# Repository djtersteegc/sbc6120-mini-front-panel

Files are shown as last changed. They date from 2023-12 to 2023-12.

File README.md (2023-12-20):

cased

Project thread at https://forum.vcfed.org/index.php?threads/sbc6120-mini-front-panel.1245272/

# Switches

The current PCB and dress panel are drilled for miniature toggles with a 6mm diameter bushing/stem.  1/4-40 switches will NOT fit since I wanted a tight fit on the dress panel and the switches are spaced to tightly to use the dress nuts.  Plus, I think this style looks nicer (same as an Altair 8800).

These are commonly listed as MTS-102 (ON-ON) and MTS-112 (ON-Momentary ON) on AliExpress.  I tried all the different red and blue models and ended up using the red ones linked below in the BOM since they had exactly the same length toggles between the two different models.  Total cost shipped to the US for twenty MTS-102 and ten MTS-112 switches was less than ten bucks, versus the $40 it would cost to buy something like E-Switch 100 Series which was the cheapest domestic option I could find.  C&K 7000 series were over $160 for 20 miniature toggles.  Maybe the action is a bit better, but at the end of the day this is a toy for me, so I would personally rather spend the budget on the next project.

# Electrical BOM

There's an interactive BOM [here](https://djtersteegc.github.io/sbc6120-mini-front-panel/ibom.html), and CSV version with footprint info [here](https://djtersteegc.github.io/sbc6120-mini-front-panel/bom.csv).

I buy pretty much everything from UTSource (for logic) or AliExpress suppliers these days with the exception of the capacitors (whatever is on clearance at Newark) and the rotary switch is only available from C&K.  If you are shopping local everything should be available from Mouser/DigiKey/Newark.

Here is a [shared Mouser cart](https://www.mouser.com/ProjectManager/ProjectDetail.aspx?AccessID=54b04bab67) with all the electrical BOM minus the toggle and slide switches which are a China only part.

C16 is a bulk storage cap for the 5V line.  I specced it at 470uF, but anything from 100uF and up will probably be fine.  You may not even really need it.

| Component | Qty  | Notes | Link |
| --- | ---- | --- | --- |
| 10nF Ceramic Capacitor | 1 | 5.08mm Lead Spacing  | [AliExpress](https://www.aliexpress.us/item/2251832786944590.html) |
| 100nF Ceramic Capacitor | 13 | 5.08mm Lead Spacing  | [AliExpress](https://www.aliexpress.us/item/2251832786944590.html) |
| 1uF Ceramic Capacitor | 1 | 5.08mm Lead Spacing  | [AliExpress](https://www.aliexpress.us/item/2251832786944590.html) |
| 470uF 16V Electrolytic Capacitor | 1 | 3.5mm Lead Spacing | [Newark](https://www.newark.com/multicomp-pro/mcmr16v477m8x9/cap-470uf-16v-alu-elec-radial/dp/39T1477) |
| 10K 1% 1/4W Resistor | 3 | | [AliExpress](https://www.aliexpress.us/item/2251832766343175.html) |
| 17.4K 1% 1/4W Resistor | 1 | | [AliExpress](https://www.aliexpress.us/item/2251832766343175.html) |
| 560R SIP9 Resistor Network | 4 | I used 510R | [AliExpress](https://www.aliexpress.us/item/2251832653789055.html) |
| 4.7K SIP5 Resistor Network | 1 | | [AliExpress](https://www.aliexpress.us/item/2251832653789055.html) |
| 4.7K SIP6 Resistor Network | 1 | | [AliExpress](https://www.aliexpress.us/item/2251832653789055.html) |
| 4.7K SIP7 Resistor Network | 3 | | [AliExpress](https://www.aliexpress.us/item/2251832653789055.html) |
| 5mm LED (Red) | 28 | | [AliExpress](https://www.aliexpress.us/item/2255800226642152.html) |
| Miniature ON-ON Toggle | 13 | MTS-102 - 6mm | [AliExpress](https://www.aliexpress.us/item/3256805560180852.html) |
| Miniature ON-(ON) Momentary Toggle | 7 | MTS-112 - 6mm | [AliExpress](https://www.aliexpress.us/item/3256802276750993.html) |
| SPDT Right Angle Slide Switch | 3 | 2.54mm Spacing | [AliExpress](https://www.aliexpress.us/item/2251832665517359.html) |
| C&K RM104772BCB Rotary Switch | 1 | 4 Position | [Newark](https://www.newark.com/c-k-components/rm104772bcb/rotary-switch-1p-0-5a-24v-45deg/dp/69AH1990) |
| 74HC05 | 1 | | |
| 74HC74 | 1 | | |
| 74HC174 | 2 | | |
| 74HC366 | 4 | | |
| 74HC373 | 2 | | |
| 7555 Timer | 1 | | |
| ATF16V8 | 1 | | |
| ATF22V10 | 1 | | |
| 2x25 2.54mm Pin Header | 1 | | [AliExpress](https://www.aliexpress.us/item/2251832485909733.html) |
| 1x2 2.54mm Pin Socket | 1 | Cut down a 40p strip | [AliExpress](https://www.aliexpress.us/item/2251832484668248.html) |
| 5.08mm 2p Terminal Block (or original 4P Molex) | 1 | KF301-2P (Power In)  | [AliExpress](https://www.aliexpress.us/item/2251832480927324.html) |

# Mechanical BOM

| Component | Qty  | Notes | Link |
| --- | ---- | --- | --- |
| 12mm M3 Standoff | 5 | SBC6120 to Panel | 3D Print |
| 15.6mm M3 Standoff | 7 | Panel to Dress Panel | 3D Print |
| 2mm High M3 Rubber Bumpers | 7 | TS-2.7 Option | [AliExpress](https://www.aliexpress.us/item/3256805089368820.html) |
| M3 x 6mm Taper Head Screws | 12 | | [AliExpress](https://www.aliexpress.us/item/3256801858523146.html) |
| M3 x 12mm Taper Head Screws  | 5 | | [AliExpress](https://www.aliexpress.us/item/3256801858523146.html) |
| M2.5 x 6mm Taper Head Screws | 6 | | [AliExpress](https://www.aliexpress.us/item/3256801858523146.html) |
| 15mm Diameter Knob | 1 | "Plum Shaft" Option  | [AliExpress](https://www.aliexpress.us/item/2251832788673272.html) |

# Other Parts

| Component | Notes | Link |
| --- | --- | --- |
| IDE to CF Adapater | CF-IDE40 or HX-168 | [AliExpress](https://www.aliexpress.us/item/3256804514420229.html) |
| DB9 to IDC 10 | May need to rewire | [AliExpress](https://www.aliexpress.us/item/3256803077047244.html) |
| 5.5 x 2.1mm DC Input Jack for 8mm Hole | DC-025M | [AliExpress](https://www.aliexpress.us/item/2255801022148508.html) |

# Case

The case is a simple two piece that holds the SBC6120 and front panel PCB securely to the bottom plate, and then the dress panel is held down by pressure around it's perimeter by the case top.  You will need supports on the bottom plate for CF, DB9, and DC power openings, but everything else can be printed without.  I would recommend a 0.2mm layer height since most dimensions are a multiple of that.  The case top and plate are 214mm x 135mm so they should be printable on something like a standard Ender 3.

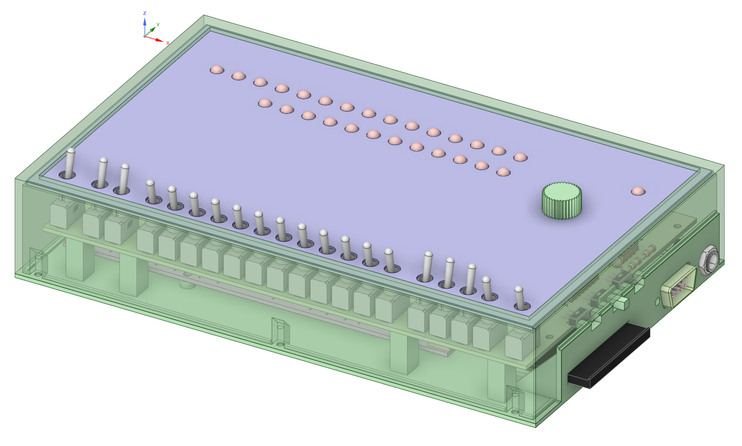
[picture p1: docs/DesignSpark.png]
DesignSpark


Total PLA filament usage for all part is ~146 grams according to Cura 5.5.

| Part | Qty  | Filament Usage (PLA) |
| --- | ---- | --- |
| Case Top | 1 | 68g |
| Bottom Plate | 1 | 64g |
| Switch Spacer | 20 | 5g |
| M3 x 12mm Standoff | 5 | 2g |
| M3 x 15.6mm Standoff | 7 | 3g |
| Slide Switch | 3 | 1g |
| Reset Button | 1 | <1g |
| Rotary Knob Adapter | 1 | 1g |
| 2.4mm Spacer for LED Installation | 4 | 1g |

Design file are in the [DesignSpark](3D/DesignSpark) folder if you would like to modify further or tweak tolerances for your printer. 

# Assembly

Build the PCB from low to high components, savings the switches, LED's, and pin headers for last. Pay attention to the Run (D28) LED, it's orientation is flipped vs. all the others. The rotary switch has a small notch, it MUST be lined up with the tick on the silkscreen. There is no other keying on this switch so it can be installed incorrectly.

Print out six copies of the [M3 x 15.6mm Standoff](3D/STL/M3%20x%2015.6mm%20Standoff.stl) if you are using the 2mm high rubber inserts on top of them, or use the [M3 x 17.6mm Standoff](3D/STL/M3%20x%2017.6mm%20Standoff.stl) if you are not.

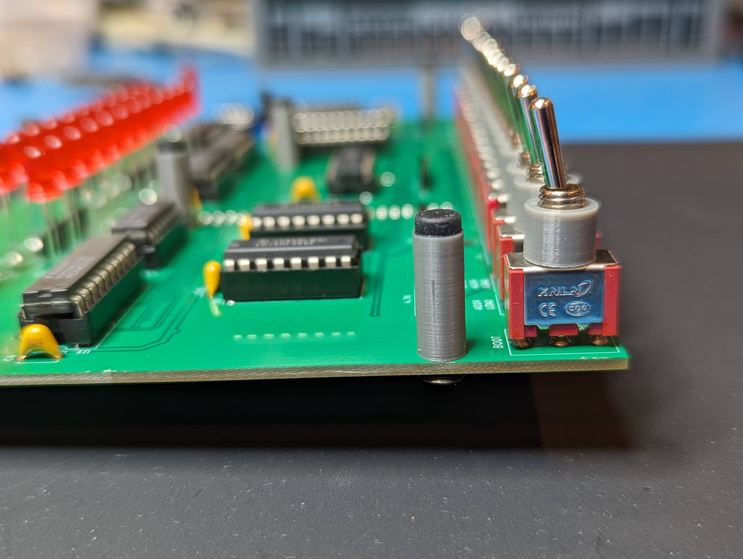
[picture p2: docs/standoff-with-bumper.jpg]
standoff-with-bumper


Also print out 20 copies of the [Switch Spacer](3D/STL/Switch%20Spacer.stl).

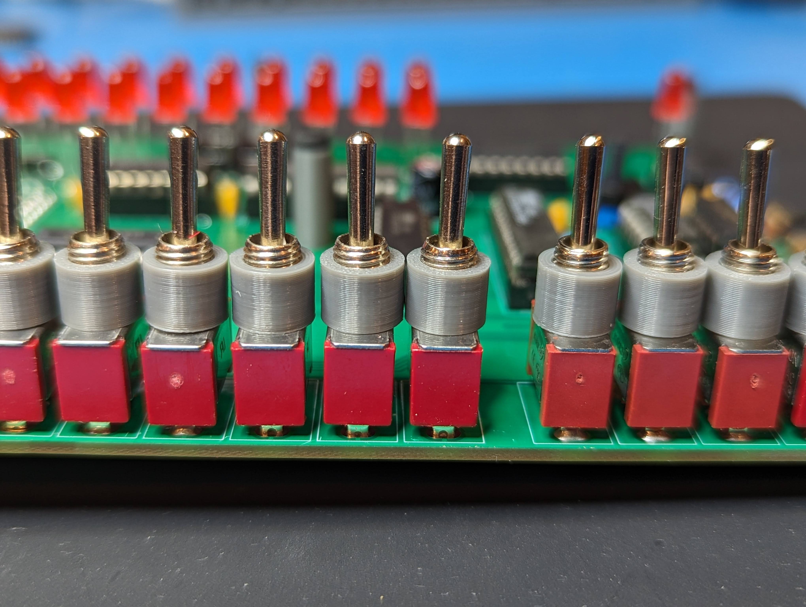
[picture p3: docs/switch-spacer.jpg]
switch-spacer


Screw the standoff into the front panel PCB, place all the switches, paying attention to the ON-ON vs. ON-(ON) models. All momentary switches should face up with the exception of the Dep (SW19) which faces down when not activated.

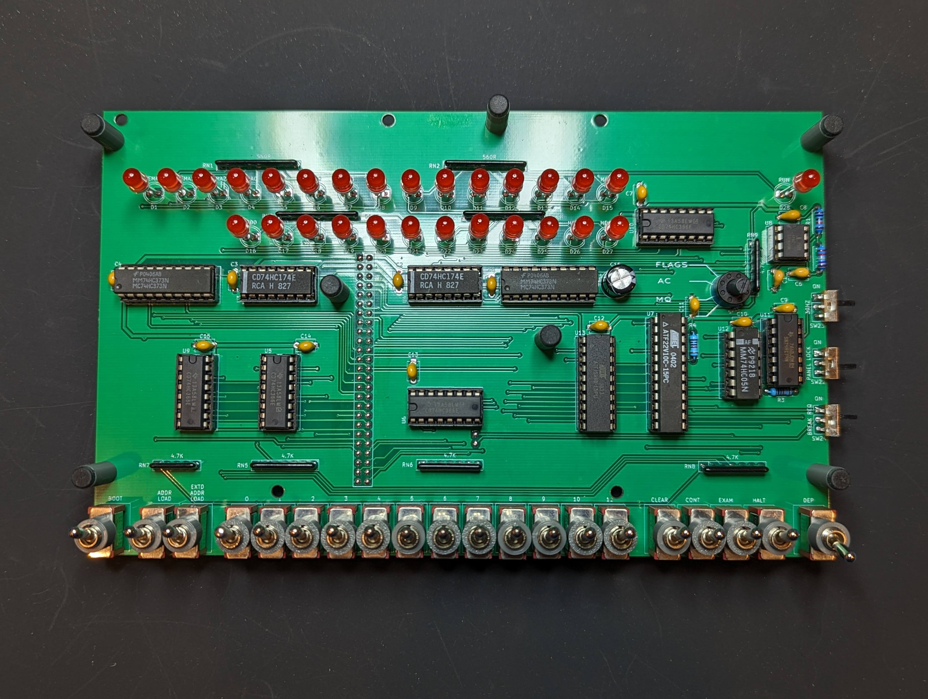
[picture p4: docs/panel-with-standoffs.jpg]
panel-with-standoffs


Slip the 20 switch spacers onto the stems, and place the dress panel so it is resting on top of the standoffs and switch spacers.  It helps to have all the switches facing up (except for DEP), slip the panel over the DEP switch, and then rotate counterclockwise to drop over the rest of the switches.  Flip everything over and rest the dress panel on something to elevate it above your work surface so the switch stems hang down.  I found a 3/4" piece of plywood worked well for this.  While supporting the dress panel, push all the switch PCB lugs down so there is no slack between the top of the switch body, spacer, and dress panel.  This will give you a consistent reveal on the front panel even if the Chinese switch tolerances are a little off and/or switch won't sit flat on the PCB due to excess sealing epoxy applied on the bottom of it.  Solder them all in.  I did one terminal each, flipped over to check my work, and then did the rest.

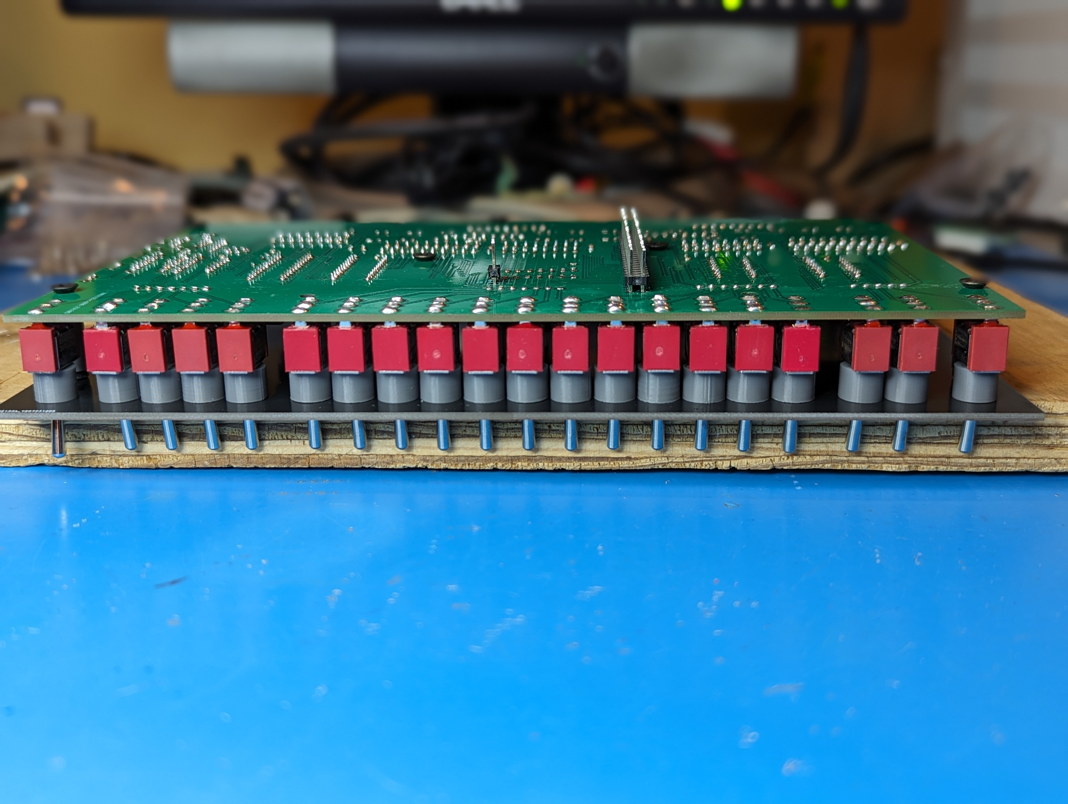
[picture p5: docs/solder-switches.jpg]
solder-switches


For the LED's, remove the dress panel, drop in the 28 LED's (since I was using cheap Chinese one's I tested them all before to make sure they were all the same brightness, they were), and then flip everything over again until the LED's poke through the dress panel holes.  I elected to have 2.4mm of reveal/protrusion on the LED's, so print out four of the [2.4mm LED Spacer](3D/STL/2.4mm%20LED%20Spacer.stl) pucks and place them under the four corners of the dress panel.  Again, the 3/4" plywood allowed the panel to lay flat while the switches overhung the edge.  Solder one leg each on the LED's, flip over to check your work, and then do the others.

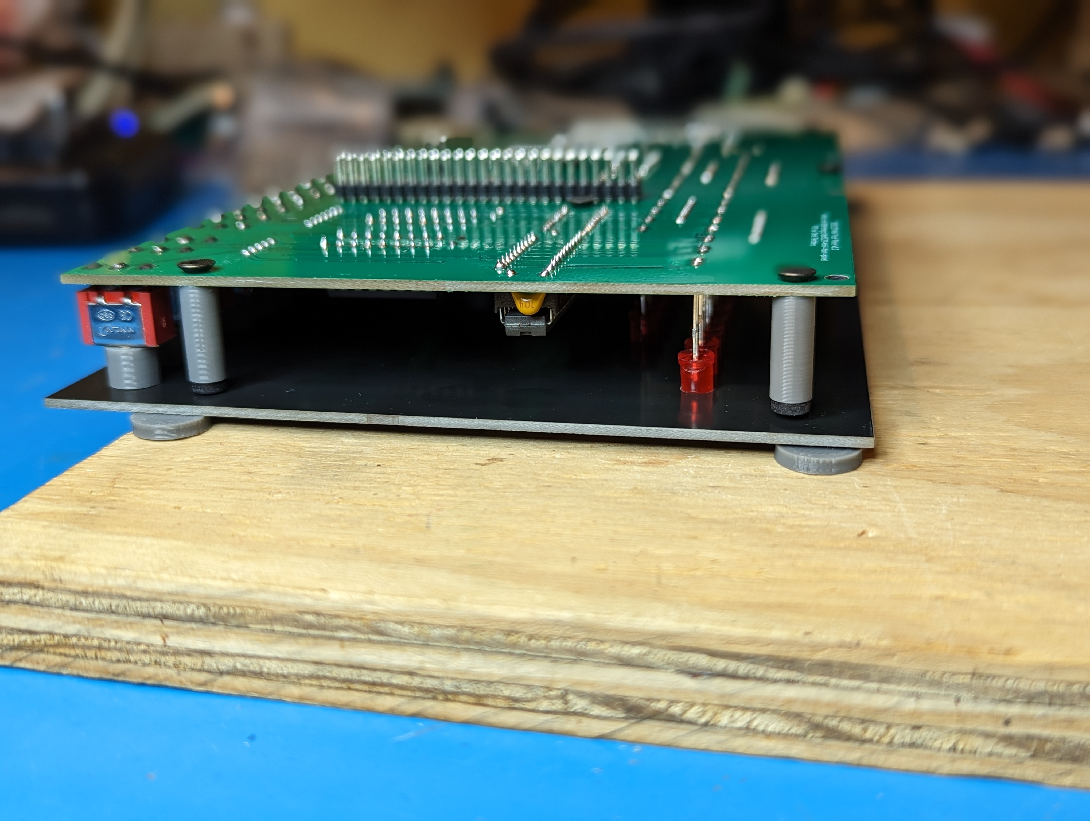
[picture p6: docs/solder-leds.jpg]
solder-leds


To install the pin headers first print and then install five [M3 x 12mm Standoff](3D/STL/M3%20x%2012mm%20Standoff.stl) on the SBC6120.  I went with 12mm instead of the more common 11mm since my socketed HD6120 was sitting at ~10mm and even after trimming the DIP socket and resistor network leads flush above it, it still seems a little tight for my tastes.  I also switched the CPREQ male header on the SBC6120 to a female header like the 2x25mm and that allowed me to fully install the male headers into both of them, and then place the front panel PCB on top and solder everything up. The header pins should be just flush with the top of the front panel PCB, not protruding like you would see with a normal install.

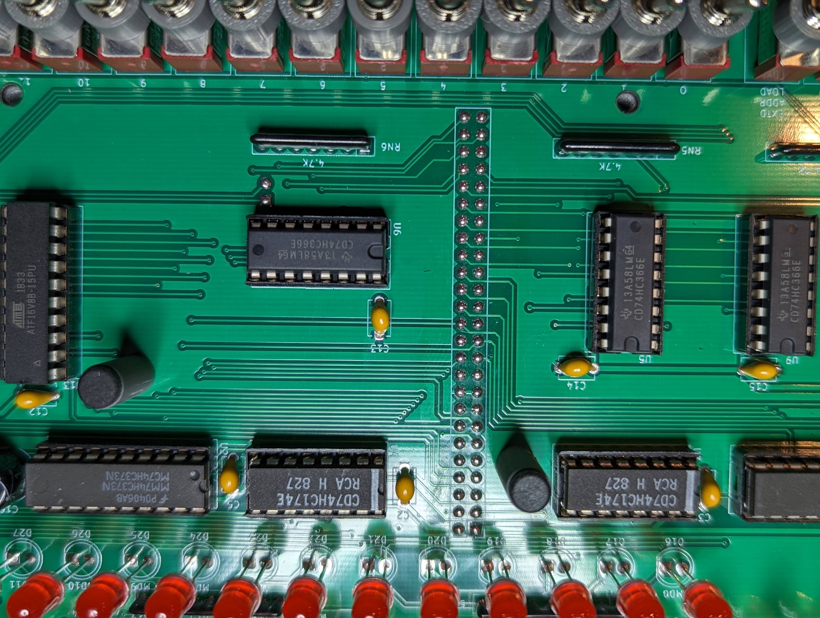
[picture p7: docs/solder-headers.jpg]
solder-headers


At this point you can install your IC's and make sure everything works.  JED files for the ATF16V8 and ATF22V10 are in the [Original STG FP6120 Files/pld](Original%20STG%20FP6120%20Files/pld) folder.  ATF16 gets decode.jed, ATF22 is control.jed. Now onto casing your new toy.

Plug the CF adapter, DB9, and DC input jack into the SBC6120.  Remove the 12mm standoffs, and install the SBC6120 to the [Bottom Plate](3D/STL/Bottom%20Plate%20-%20CF-IDE40.stl) with five M3x12mm screws into the bottom of the standoffs.

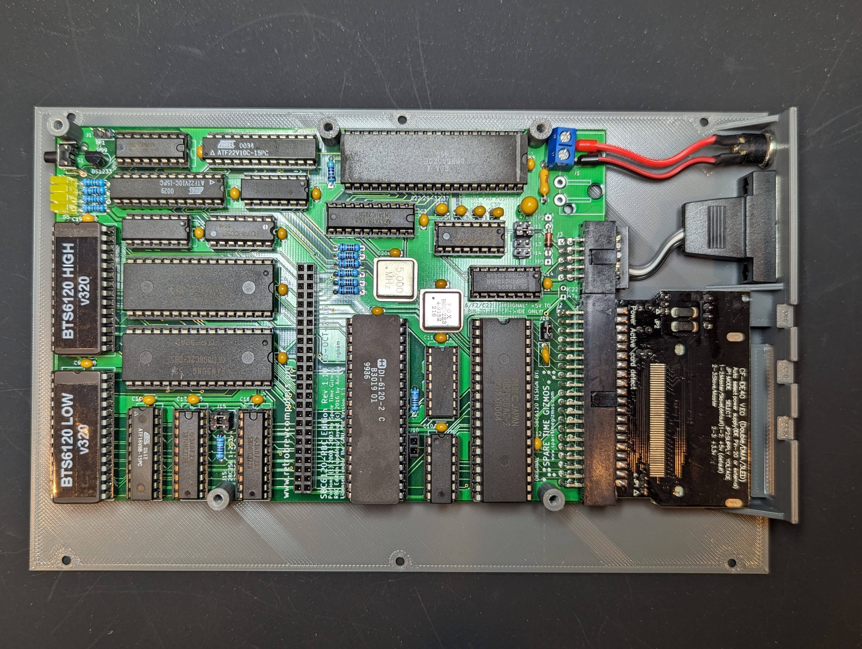
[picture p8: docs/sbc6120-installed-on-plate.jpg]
sbc6120-installed-on-plate


Slip three of the [Slide Switch](3D/STL/Slide%20Switch.stl) extenders onto the switches and install the front panel PCB onto the SBC6120.  Secure with five M3x6mm screws.

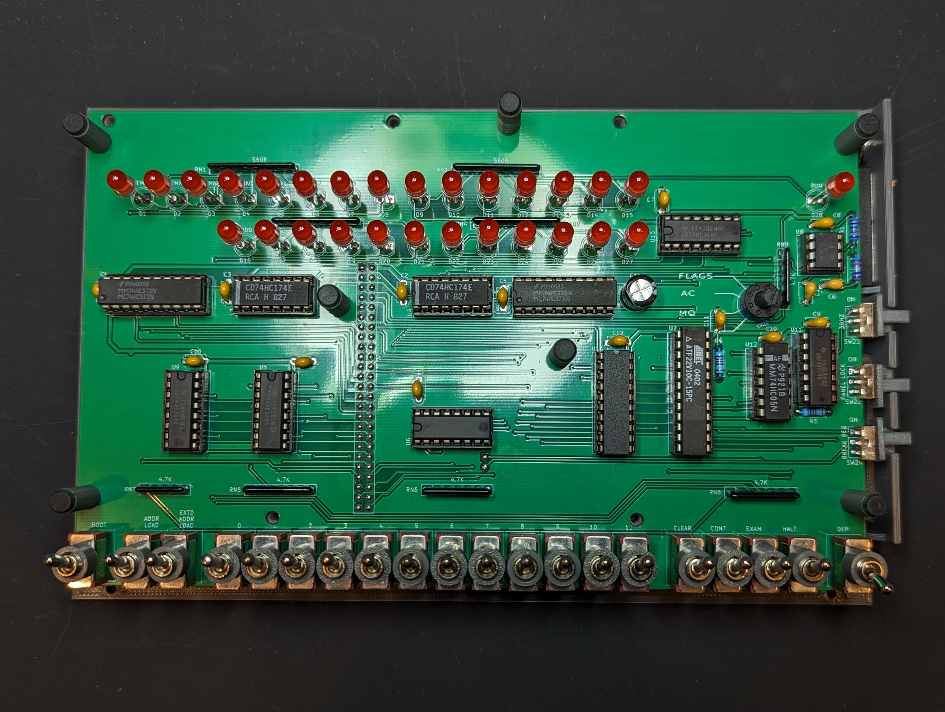
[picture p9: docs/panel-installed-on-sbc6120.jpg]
panel-installed-on-sbc6120


Angle the dress panel PCB into the [Top Case](3D/STL/Top%20Case.stl) and make sure it fits in the recess at the top.

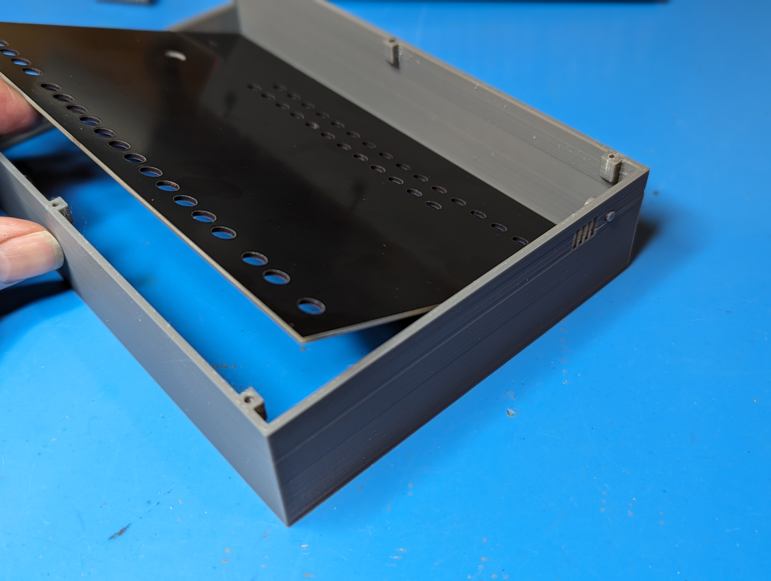
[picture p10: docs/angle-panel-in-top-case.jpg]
angle-panel-in-top-case


Install the [Reset Button](3D/STL/Reset%20Button.stl) extender into the hole and then let the dress panel rest at the bottom of the top case on top of the six lugs for the screws. Place over the switches with a similar counterclockwise twisting motion as above, and then push the top case all the way down.

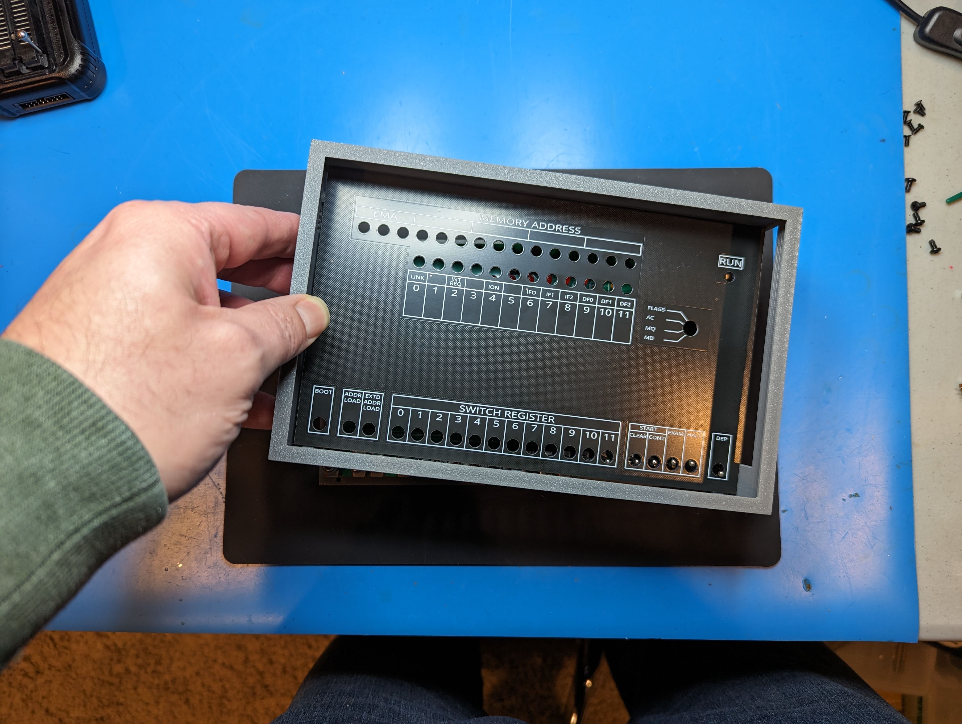
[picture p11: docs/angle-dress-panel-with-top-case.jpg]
angle-dress-panel-with-top-case


Secure with six M2.5x6mm screws through the bottom of the case.

Finally push the splined portion of the [Rotary Knob Adapter](3D/STL/Rotary%20Knob%20Adapter.stl) into your 6mm knob with the D cut opposite the indicator mark on the switch, and line up the D cut on the rotary switch.

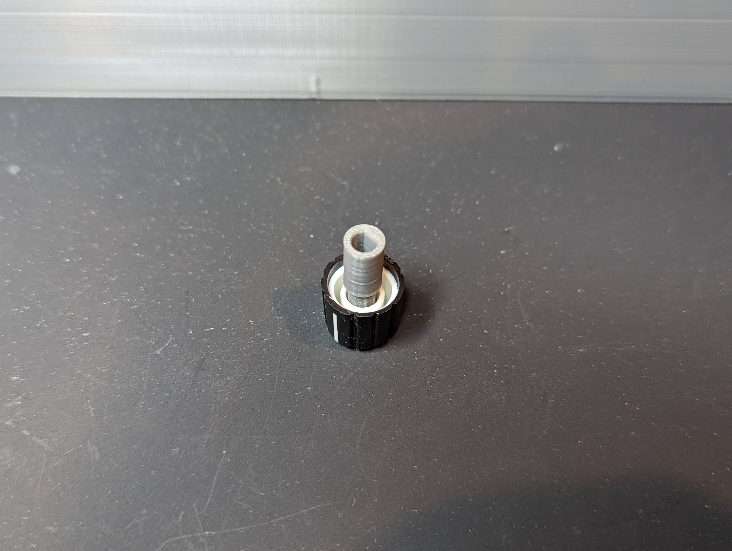
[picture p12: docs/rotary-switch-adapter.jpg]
rotary-switch-adapter


# How do I get some PCB's?

If you are in the US, hit me up on the VCF forum thread above and if I have any extras, I can drop some in the mail for less than the cost of a small run at JLCPCB (size and shipping drive up the costs here).  Otherwise, there are gerber files available for use at your favorite PCB fab.

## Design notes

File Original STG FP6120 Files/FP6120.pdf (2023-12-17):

Copyright 2003 by Spare Time Gizmos.

### Visit our web site at www.SpareTimeGizmos.com

Permission is granted to copy, distribute and/or modify this document under the terms of the GNU Free Documentation License, Version 1.1 published by the Free Software Foundation; with no invariant sections; with the front cover text “Portions Copyright 2001-2003 by Spare Time Gizmos” and our URL, and with no back cover text. A copy of this license may be obtained from http://www.gnu.org/licenses/fdl.txt.

FP6120

# SBC6120 FRONT PANEL

# USER'S MANUAL

# First Edition

# CONTENTS

Page i

Spare Time Gizmos | FP6120 User's Manual

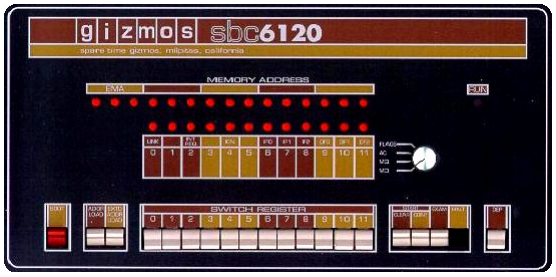
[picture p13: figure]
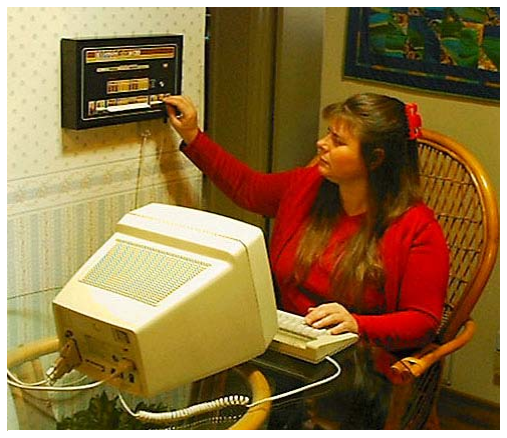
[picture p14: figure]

10/24/2003 8:39 PM | Page 1

# 1 OVERVIEW

The FP6120 adds a traditional PDP-8/E style Programmer’s Console to any SBC6120 system. Twenty seven
LEDS provide
continuous
display of the
current
memory
address as
well as
memory or
register
contents, and
a additional
LED displays
the running or
halted state of
the processor.
Twelve data
switches allow
for direct entry of binary data and an additional eight switches provide program control functions
including BOOT, ADDRESS LOAD, EXTENDED ADDRESS LOAD, CLEAR, CONTINUE, EXAMINE, DEPOSIT
and HALT.

The FP6120 is designed as a peripheral device which plugs into the standard SBC6120 expansion bus, however because of its physical size the SBC6120 actually mounts directly to the back of the front panel. Additional space is available on the back of the FP6120 to mount another I/O board as well as either a CompactFlash memory card or a standard 2½” laptop hard disk drive. Finally, the FP6120 contains a switching power supply which can supply all necessary power for the SBC6120, one or two daughter boards, and the FP6120 itself from a single unregulated source of +9 to +12VDC.

The front panel façade you see in these photos was professionally screen printed in five colors and then laser cut for the switch openings. The entire FP6120 and SBC6120 assembly, including a hard disk drive, is less than 2” thick and can be framed like a painting and hung on the wall. Just imagine it – a complete PDP-8/E clone, including disk drive, hanging on the wall above your desk!

### 1.1 REGULATORY WARNING

In the United States, the Federal Communications Commission requires that devices that use and radiate radio frequency energy be certified in accordance with CFR Title 47, Parts 2 and 15. Other countries will have different requirements.

Figure 1 - The SBC6120 Front Panel

Figure 2 - Complete SBC6120/FP6120 combination hanging on the wall

The FP6120 design is not in finished product form and has NOT been approved by the FCC or any other regulatory agency worldwide. The user understands that approvals may be required prior to the operation of the FP6120, and agrees to utilize the FP6120 in keeping with all laws governing its operation in the country of use.

### 1.2 WARRANTY

SPARE TIME GIZMOS OFFERS NO WARRANTY, EXPRESS OR IMPLIED, AS TO THE RELIABILITY OR ACCURACY OF THE FP6120 DESIGN. SPARE TIME GIZMOS OFFERS NO WARRANTY, EXPRESS OR IMPLIED, AS TO THE ACCURACY OF THE INFORMATION PRESENTED IN THIS DOCUMENT. SPARE TIME GIZMOS OFFERS NO WARRANTY, EXPRESS OR IMPLIED, AS TO THE SUITABILITY OR CORRECTNESS OF ANY SOFTWARE OR FIRMWARE SUPPLIED IN CONJUNCTION WITH THE FP6120.

SPARE TIME GIZMOS MAKES NO REPRESENTATIONS AS TO THE SUITABILITY OF THE FP6120 FOR ANY APPLICATION. IT IS SOLELY AND EXCLUSIVELY YOUR RESPONSIBILITY TO EVALUATE THE ACCURACY, COMPLETENESS, AND USEFULNESS OF THE FP6120 AND ALL RELATED DESIGNS, SOFTWARE, AND OTHER INFORMATION PROVIDED BY SPARE TIME GIZMOS. THE ENTIRE RISK AS TO THE USE AND PERFORMANCE OF THE FP6120 IS ASSUMED SOLELY BY YOU.

NO REPRESENTATION OR OTHER AFFIRMATION OF FACT, INCLUDING, BUT NOT LIMITED TO, STATEMENTS REGARDING CAPACITY, PERFORMANCE OF PRODUCTS, OR SUITABILITY FOR USE, WHETHER MADE BY SPARE TIME GIZMOS EMPLOYEES OR OTHERWISE, WILL BE DEEMED TO BE A WARRANTY FOR ANY PURPOSE, OR GIVE RISE TO ANY LIABILITY ON THE PART OF SPARE TIME GIZMOS.

THE WARRANTIES AND CORRESPONDING REMEDIES AS STATED IN THIS SECTION ARE EXCLUSIVE AND IN LIEU OF ALL OTHERS, WRITTEN OR ORAL. SOME JURISDICTIONS DO NOT ALLOW THE EXCLUSION OF IMPLIED WARRANTIES, SO THE ABOVE EXCLUSION MAY NOT APPLY TO YOU. THE LIMITED WARRANTIES AND CONDITION REFERENCED ABOVE GIVE YOU SPECIFIC LEGAL RIGHTS. YOU MAY HAVE OTHERS, WHICH VARY FROM JURISDICTION TO JURISDICTION.

IN NO EVENT SHALL SPARE TIME GIZMOS OR ITS EMPLOYEES BE LIABLE FOR ANY COSTS OR DIRECT, INDIRECT, PUNITIVE, INCIDENTAL, SPECIAL, CONSEQUENTIAL DAMAGES OR ANY OTHER DAMAGES WHATSOEVER INCLUDING, WITHOUT LIMITATION, DAMAGES FOR COSTS OF PROCUREMENT OF SUBSTITUTE GOODS OR SERVICES, LOST PROFITS, LOSS OF DATA, INTERRUPTION OF BUSINESS, OR LOSS OF USE, ARISING OUT OF OR IN ANY WAY CONNECTED WITH THE USE OR PERFORMANCE OF THE FP6120 OR YOUR RELIANCE ON THE FP6120 OR RESULTS FROM MISTAKES, OMISSIONS, INTERRUPTIONS, DELETION OF FILES, ERRORS, DEFECTS, DELAYS IN OPERATION OR TRANSMISSION, OR ANY FAILURE OF PERFORMANCE WHETHER BASED ON CONTRACT, TORT, STRICT LIABILITY OR OTHERWISE, EVEN IF SPARE TIME GIZMOS HAS BEEN ADVISED OF THE POSSIBILITY OF DAMAGES. BECAUSE SOME STATES/JURISDICTIONS DO NOT ALLOW THE EXCLUSION OR LIMITATION OF LIABILITY FOR CONSEQUENTIAL OR INCIDENTAL DAMAGES, THE ABOVE LIMITATION MAY NOT APPLY TO YOU.

IN NO EVENT SHALL SPARE TIME GIZMOS' LIABILITY, IN THE AGGREGATE, EXCEED THE SUMS ACTUALLY PAID BY YOU TO SPARE TIME GIZMOS AND ACCEPTED BY SPARE TIME GIZMOS FOR THE USE OF THE
FP6120.

# 2 CONSTRUCTION

If you haven’t already, then please read the “Assembly” section of the SBC6120 User’s Manual before reading this. Many of the points made there, particularly the section on “Sockets and Soldering” apply equally well to the FP6120!

### 2.1 ERRATA

There are no known errors in Revision D of the FP6120 board.

### 2.2 FIRMWARE NOTES

The FP6120 requires that your SBC6120 have BTS6120 v266 or later. This version may be downloaded from the Spare Time Gizmos web site if you need to upgrade your EPROMs. The FP6120 does not require any changes to the SBC6120 PLDs.
If you intend to use the FP6120 with Jim Kearney's IOB6120, there are more issues you should be aware of:
- The IOB6120 requires a hardware upgrade to work reliably with the FP6120. The last few IOBs assembled and sold by Jim already had this modification, and if your IOB contains a 74HC373 part then yours should be OK. If it contains a 74ACT373, however, talk to Jim about the details of a fix.
- Early versions of the FPGA bit stream include an implementation of the PDP-8 switch register which will conflict with the FP6120 and prevent the front panel switches from working. The latest version of the FPGA bit stream has the switch register removed and can be obtained from http://www.jkearney.com/sbc6120/iob6120.htm. Follow the instructions in Jim’s IOB6120 manual for downloading new FPGA bits to the Flash ROM on the IOB6120.
- Although the FP6120 works with any SBC6120 PLD version, the IOB requires revision B or later of the IOT1 PLD. Spare Time Gizmos is currently shipping revision C of this part. Contact Jim directly for more information on these IOB updates.

### 2.3 SBC6120 MODIFICATIONS

SBC6120 Revision D PC boards require that a jumper be added to connect the LXMAR signal to pin 22 of the expansion connector. Revision E and later PC boards incorporate this change and do not require modification. The revision of your PC board can be found in the etch on the solder side underneath the IDE connector – look for the words “SBC6120-2x Copyright 200? Spare Time Gizmos”. The letter “x” after the SBC6120-2 is the revision of your board.
Figure 3 shows the proper way to modify a revision D PC board. Carefully count the pins on the bus connector to locate pin 22, and then count down four more pins to locate the trace that connects U8 pin 23 to U5 pin 34. This trace is LXMAR, and you need to solder a short jumper from it to pin 22 of the bus connector. Since pin 22 was previously unused, no other traces need to be cut.

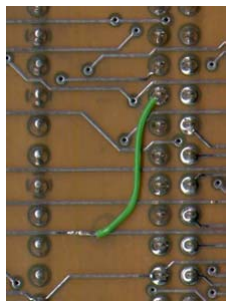
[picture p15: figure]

Spare Time Gizmos is currently shipping Revision E of the SBC6120 PC boards. These boards, and later ones, already incorporate this

Figure 3
LXMAR Jumper connection and do not require modification.

### 2.4 PARTS SELECTION

### 2.4.1 Finding Compatible Switches

The FP6120 is designed to use C&K P/N 7101J60V6BE1 (ON-NONE-ON) and 7108J60V6BE1 (ON-NONE-MOM) SPDT PCB mount paddle switches. It’s certainly possibly to find exact matches for these part numbers, however there are a number of other switches that can also be used. It's handy to understand something about the C&K nomenclature so you can figure out possible substitutions.
J60 is the actuator style, in this case a 0.460" wide lever. Other styles in the same width, such as the J1, J15 or J50 rockers, will fit the PC board but probably won't work with the plastic front facade. It’s also worth nothing that the actuators are interchangeable between the C&K paddle and rocker switches, so if you have a cheap source for ON-NONE-ON paddle switches, it’s possible to remove the paddles from them and install them on the corresponding ON-NON-(MOM) rocker switches.
V6 refers to the PCB mount frame used. The V61 frame is for our purposes identical and will work without problems. The V3 and V31 frames are similar but with different mounting hole spacing, however the FP6120 PC board contains extra holes so that the V3 and V31 frames will also fit without problems. The V2 and V21, V4 and V41, V7, V8, and V9 frames will all fit the PC board however these frames are different heights and will not mate properly with the plastic front panel faceplate.
B refers to the contact material (gold in this case), which is unimportant as far as mechanical concerns go. The only other one you're likely to see is Q, silver.
The final 1 at the end of the P/N is the actuator color. 1 is White, 2 is Black, and 3 is Red. Naturally this makes to mechanical difference, but, for example, you might not like the way a row of all red switches looks!
Finally, C&K is not the only possible switch source. Other manufacturers, such as NKK, E-Switch, CTS, etc. make switches that are generally compatible with their C&K counterparts. These manufacturers usually have some sort of cross reference guide to help you find equivalent part numbers.

### 2.4.2 The LED Bar

The LED Bar is a piece of plastic, approximately 12.4"x1.1" and 5/8" thick with holes drilled in it for every LED. It mounts solder in swage standoffs placed on the PC board with #4-40 screws and serves two purposes. First, the LED bar serves as an "aligner" to keep the LEDs straight and lined up with the corresponding holes in the faceplate. Second, the bar isolates the LEDs so that the light from, say, the MA3 LED doesn't also leak out the opening for the MA2 or MA4 LEDs. You can build your own LED bar, or you can purchase a nicely milled and drilled one all ready to go directly from Spare Time Gizmos, part number FP6120-LBK.

### 2.4.3 The Faceplate

The faceplate is a piece of 3/16” acrylic plastic, approximately 8 ½” by 15”, silk screened with the front panel graphics and cut to clear the switches. It mounts to the front panel PC board with eight #4-40 by 5/8” standoffs which are permanently attached to the faceplate. You can purchase a faceplate separately from Spare Time Gizmos, part number FP6120-FPK.
In the faceplate supplied by Spare Time Gizmos the graphics are screen printed, with no less than five colors and five separate printing steps, onto a 15 mil (that's 0.015"!) polycarbonate film.

In a separate step a 3/16" thick piece of acrylic is laser cut to size and drilled for the mounting holes. The mounting hardware is then attached to the back of this panel and permanently glued into place. In yet a third separate step, a sheet of adhesive film is cut to size and then stamped with a custom made die to cut out circular openings in the exact size and position of the LED windows. Now, those three separate pieces, the film with the graphics, the adhesive, and the 3/16" panel are all laminated together into a single piece and finally the entire thing is laser cut again for the switch openings.
One nice feature of process is that the faceplate is all one piece when you get it, so there's no complex assembly required on your part (like aligning and sandwiching a film between two sheets of plastic). Another nice feature is that the silkscreen is actually printed on the back side of the polycarbonate film, so that when it's assembled all the printing is protected from wear and scratches by the 15 mil thick film. And finally, this style of assembly hides leaves the heads of the mounting screws hidden beneath the film, so there’s nothing to mar the faceplate graphics.

### 2.4.4 Integrated Circuits

Either the 74HC366 or 74HC368 Hex Inverting Tri-State buffer may be used in this circuit.¹
The
7555 CMOS timer is known by many different part numbers depending on the manufacturer. The actual 7555 part number is used by Harris/Intersil, however the TLC555 (manufactured by Texas Instruments) is also quite common. The Power Trends (now part of Texas Instruments) switching regulator is available in either a 2A/10W version, the PT78HT205H or a 3A/15W version, the PT78HT305H. Either one will fit the PC board, and you may wish to use the 3A/15W device if you plan to also power a hard disk drive.²

### 2.4.5 Other Parts

C2 and C7 are 0.01 µF monolithic capacitors and are shown on the schematic and PC board, however they are not needed and may be omitted from the FP6120. It does no harm to install them, though, and if you already have then there’s no need to remove them.

### 2.5 ASSEMBLY INSTRUCTIONS

In the following instructions, the "front" of the PC board refers to the component side (the one with the silk screen) and the "back" of the PC board is the solder side (opposite the silk screen). The "top" of the PC board is the edge that contains the Spare Time Gizmos logo, and the "bottom" of the PC board is the edge with all the switches.

### 2.5.1 Swage Standoffs

Solder in, swage, ⅛” by #4-40 standoffs are used to mount the LED bar, the SBC6120 and an I/O daughter board (if any). Some of these standoffs are mounted on the front (component) side of the PC board and some are mounted on the back (solder) side, and it’s very important to identify the correct holes for each standoff.

1 If you purchased the kit version, either part may be supplied. 2 The PT78HT205H is supplied with the full kit.

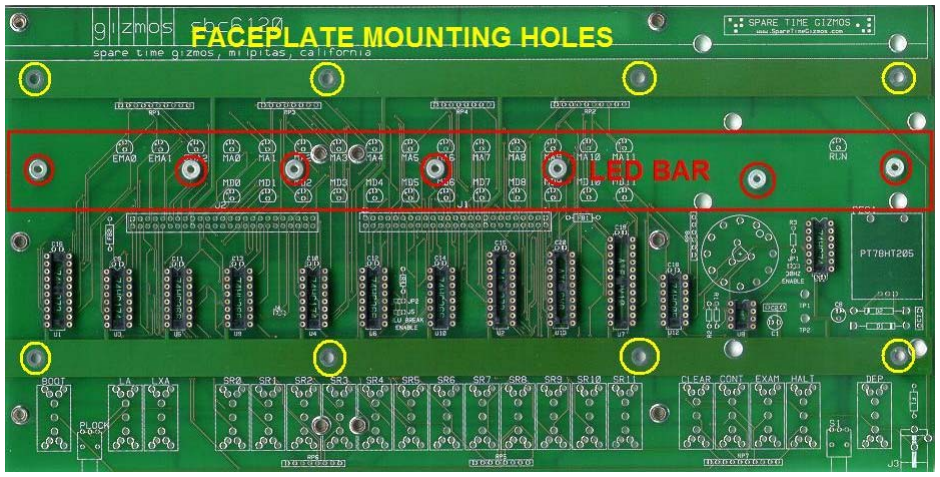
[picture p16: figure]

Figure 4 -Mounting Holes (Component Side)

Figure 4 shows the component side of a partially assembled FP6120 PC board. The outline of the LED bar is shown and the seven swage standoffs used for mounting the LED bar are circled. These standoffs are all mounted with their threaded parts on the front (component) side of the PC board and are soldered on the back (solder) side.
Figure 4 also shows the eight mounting holes used by the faceplate assembly. These holes do not use swage standoffs!
Figure 5 shows the solder side of the same FP6120 PC board and the outlines of the SBC6120 board, the I/O board, the CompactFlash adapter, and the IDE disk drive. The colored circles indicate the corresponding mounting holes for each device. The SBC6120 and I/O board each use five swage standoffs, and in this case the standoffs are installed with their threaded part on the solder side of the PC board and are soldered on the component side.

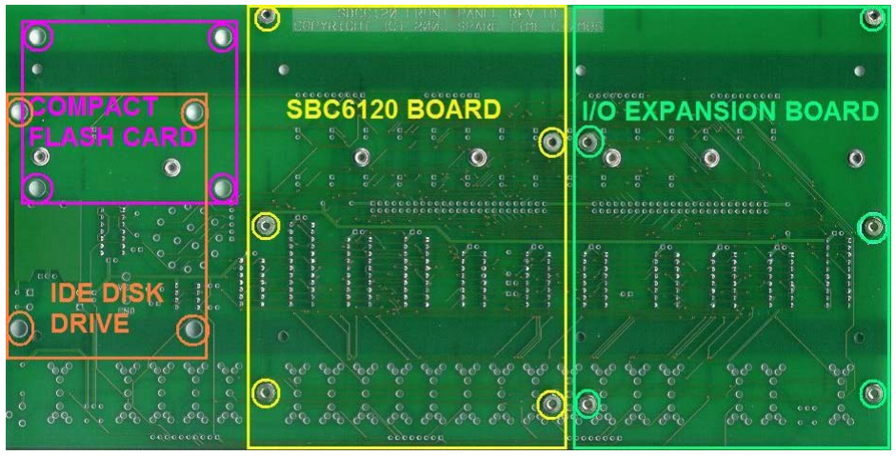
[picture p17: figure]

Figure 5 - Mounting Holes (Solder Side)

### 2.5.2 Small Components

9 Mount the small components, such as the IC sockets, resistors, capacitors, and the voltage regulator REG1, next. Above all, do not mount the LEDs, switches, or connectors now.
9 All the resistor packs used are the type that has one common pin. Be sure to mount them with the common pin as #1, which is indicated by a square pad on the PC board. You may wish to socket RP1 thru RP4 if you want to change them later to adjust the LED current³ .
RP5 thru RP8 are always 4.7K and there's no point in socketing them.

### 2.5.3 Power Switch, Panel Lock and Power Connector

9 The power switch (S1), panel lock switch (PLOCK) and DC power connector (J3) may all be mounted directly to the PF6120 PC board. However, if you plan to install the FP6120 in an enclosure of some kind it may be more convenient to mount these switches off the PC board, or even remove them all together.
The panel lock switch (PLOCK) may be omitted without problems (it will default to unlocked if it is not installed) or you may connect it to an external switch (perhaps a key switch or some kind) using wire jumpers.
If you mount the power switch (S1) elsewhere it’s probably easier to simply wire it in series with the power supply rather than connecting it to the pads for S1 on the PC board. If you do this, be sure to solder a wire jumper between the pads for S1 on the FP6120 PC board to provide continuity for the power circuit!
If you mount the DC power jack, J1, off the PC board be careful of the polarity – the center pin is positive and the sleeve is negative!

3 Sockets for these resistor packs are not included in the FP6120 full kit.

### 2.5.4 Bus Connectors

9 J2 is a female, non-stacking bus connector which you should mount on the solder side of the PC board. You will be soldering its pins on the component side.
9 J1 is a stacking bus connector which you should mount with the female part on the component side of the PC board. The stacking pins should extend thru the solder side, and you solder it normally, on the solder side. Try to keep the solder down around the pads when soldering this connector, and don't get any solder on the ends of the pins.
9 J5 is a two pin female header which mates with the console CPREQ header on the SBC6120. That’s the two pin header immediately to the right of the HD6120 CPU chip. J5 should be installed on the back side of the front panel PC board. You may also need to replace the header on the SBC6120 with one that has longer pins (the wire wrap style are plenty long) to ensure that it makes connection with J5⁴
Having said that, be sure that the pins aren't too long - you could crack the PC board when you tighten the mounting screws on the SBC6120! In particular, if you do you replace the header on the SBC6120 with a wire wrap version, the pins will be way too long! The best procedure is to insert the wire wrap header in the SBC6120 PC board without soldering it (you can use tape to hold it in place) and then temporarily mount the SBC6120 on the back of the FP6120 PC board (see section 0). You can push the pins on the wire wrap header thru the SBC6120 PC board until the correct length is achieved. Then solder them, remove the SBC6120 from the FP6120, and cut off the excess pin length.
Don't confuse J5 with JP2 (the SLU Break Enable jumper) on the front panel PC board. JP2 is closer to the resistor and is a standard two pin header installed on the top of the front panel PC board. J5 is the pair of holes closest to the switch register.
9 J4 serves a similar purpose connecting to the CPREQ header on the IOB6120 board. In this case you should have installed a female header on the back side of your IOB and the male header on the back side of the front panel. This arrangement allows you to plug the IOB6120 into the SBC6120 directly, without a front panel, if you ever want to. You’ll have the same problems with the length for this pair of headers that you did for the SBC6120, and you can use the same techniques to solve it.

At this point you should have all electronic components mounted EXCEPT the toggle switches, rotary switch and LEDs.

### 2.5.5 LED Bar and LEDs

9 Mount the plastic LED spacer bar using seven #4-40 x ⅝” flathead screws into the corresponding swage standoffs. The front of the LED bar is countersunk to fit the screw heads and the back side of the LED bar is recessed to fit the swage standoffs. The LED bar should fit snugly against the PC board and the screw heads should not protrude above the top of the LED bar.
The LED Bar supplied by Spare Time Gizmos has five extra holes which are used to secure the piece during the machining process. These holes are easily identified because they are not countersunk or recessed, and they should be left empty.
9 Mount a group of five or six LEDs by pushing them thru the light bar from the front, Be sure to get the polarity right - the long lead goes to the hole marked with a + on the silk screen,

4 A two pin wire wrap header for replacing the one on the SBC6120 board is included in the FP6120 full kit.

After you've installed a few LEDs, carefully (so that they don't fall out!) flip the PC board over and lay it upside down on the workbench so that it is resting on the LED bar..
From the solder side, push the LEDs down until the LED face is pressing against the bench -this will ensure that the face of each LED is exactly flush with the surface of the bar. Solder one lead on each LED, flip the assembly over and double check that everything is positioned properly.
When you're satisfied with the LED position solder the other leads, and then repeat this procedure for another group of LEDs. Continue until all 26 are installed.
Figure ?? shows a picture of the FP6120 with the LED bar, LEDs and other small components installed. Notice that the LEDs are flush with the LED bar – be especially careful that the LEDs do not protrude beyond the face of the LED bar, because they might crack the plastic faceplate when it is installed.

### 2.5.6 Switches

9 Install the paddle switches next – SR0 thru SR11 and HALT are "snap action", ON-NONE-ON switches and the rest are all momentary. The momentary switches should be installed so that their toggles point upward in the rest position; that is, you should push their levers down to activate them. The sole exception to this rule is the DEP switch which, by tradition, is installed "upside down" so that you have to lift the paddle to activate it.
9 Before installing the rotary switch you will need to cut the shaft to a length of approximately 0.400"??, as measured from the top of the threaded sleeve. To improve the front panel clearance, remove the lock washer from the shaft of the rotary switch. Do not remove the tang washer (that’s the washer with the little finger on it) and be sure to replace the nut after removing the lock washer; it prevents the tang washer from falling out. The tang washer limits the rotation of the switch to four positions, so if you do accidentally remove the tang washer, be sure to replace it with the finger in the hole marked #4.
Notice that the rotary switch has a small round plastic "post" on the top surface that serves as a key. This key is shown on the PC board silk screen and should be about the 2 o'clock position when the switch is correctly installed.
Clearance for the rotary switch is limited, so be sure it is absolutely flat against the PC board when you install it. At first solder only two terminals on opposite sides of the switch, and then use your soldering iron to re-melt the solder on those two terminals while you press the switch down against the PC board with your other hand. Visually inspect it to make sure that it is snug against the PC board before soldering the other terminals.

### 2.6 INSTALLING THE SBC6120 AND OTHER DAUGHTER BOARDS

The SBC6120, and any I/O daughter board such as the IOB6120 mount to the back (solder) side of the FP6120 using #4-40 ½” nylon spacers inserted in the swage standoffs soldered to the PC board. The ½” length of the spacer plus the ⅛” length of the swage gives exactly the correct 0.625” height for these boards that will allow the bus connectors to mate properly. #-4-40 ⅜” nylon screws are used to complete the job.
When installing either the SBC6120 or the IOB6120, be certain that the CPREQ headers mate correctly – the pins should line up with the corresponding female header and the pins must not be too long or too short. See section 2.5.4 for a complete description.

Note that the SBC6120 is installed in the center of the FP6120 “face down” – that is, with the component of the SBC6120 facing the solder side of the FP6120. The I/O expansion board, if any, installs on the right side of the back of the FP6120 “back to back” – that is, with the solder side of the expansion board facing the solder side of the FP6120. Figure 6 illustrates the correct installation of the SBC6120 and an IOB6120 daughter card.

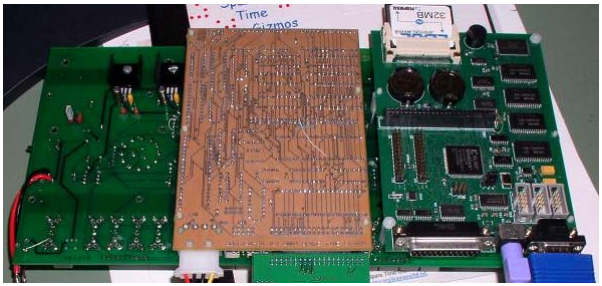
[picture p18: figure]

Figure 6 - Assembled FP6120, SBC6120 and IOB6120

# 3 OPERATION

### 3.1 INDICATORS

The FP6120 contains a total of twenty eight LED indicators. These indicators provide a continuous display of the memory address, memory data and the contents of several internal processor registers, as described in table Table 1.

### MEMORY ADDRESS

Displays the currently addressed memory location while the processor is running, the contents of the program counter when the processor stops, and the address of the location corresponding to the memory data displayed when the rotary switch is set to the MD position.
EMA | These LEDs are unused in conjunction with the MEMORY ADDRESS LEDs to display a full fifteen bit memory address.
DATA | These twelve LEDs can display either the contents of the memory location indicated by the MEMORY ADDRESS and EMA LEDs, or the contents of the internal processor accumulator or multiplier quotient registers, or the processor status flags, as selected by the position of the rotary switch.
RUN | This LED is ON when the processor is executing a main memory program and it is OFF when BTS6120 has control.

Table 1 - Front Panel Indicators

### 3.2 SWITCHES

The FP6120 contains a total of twenty paddle switches for memory modification, program control and data entry functions. Most switches are effective only when the RUN LED is OFF (i.e. BTS6120 is in control) and only the switch register, SR0..SR11, the rotary switch, and the HALT switch are enabled when the RUN LED is ON. Table 2 describes the function of each switch.

SR0
…
SR11
| These switches can be used to enter twelve bits of data directly into the PDP- 8 program. They may be read by the standard OSR or LAS instructions. These switches are also used in conjunction with other front panel switches to load memory addresses, data, or flags.
BOOT | Pressing this switch twice executes the default bootstrap which searches for a valid boot block on the ID and VM devices. This action is exactly equivalent to typing the BTS6120 B command without arguments.
| NOTE The BOOT switch must be pressed twice, without any other intervening switch or command, to take effect.

### ADDR LOAD

| Pressing the ADDRess LOAD switch loads the contents of the switch register into the program counter. The address is displayed on the MEMORY ADDRESS LEDs and, if the rotary switch is set to the MD position, the contents of the corresponding memory location is displayed on the DATA LEDs.

### EXTD ADDR LOAD

Pressing the EXTendedD ADDRess LOAD switch loads the contents of switch register bits 6..8 into the instruction field register and switch register bits 9..11 into the data field register. The remaining bits of the switch register are ignored. The EMA LEDs will display the new instruction field and, if the rotary switch is set to the MD position, the contents of the corresponding memory location is displayed on the DATA LEDs.
CLEAR | Pressing the CLEAR switch clears the internal processor registers including the AC, MQ, IF, DF, LINK, SP1 and SP2. It also initializes all peripheral devices by executing the equivalent of a CAF (Clear All Flags) instruction. Note that the CLEAR switch does not change the contents of the program counter.
CONT | Pressing the CONTinue switch starts the main memory program running at the location contained in the program counter. All processor registers retain their original contents. This switch is exactly equivalent to the BTS6120 C command. The RUN LED is turned on by this switch.
EXAM | Pressing the EXAMine switch increments the program counter and then displays the new address on the MEMORY ADDRESS LEDs. If the rotary switch is set to the MD position then the contents of this location will be displayed on the DATA LEDs.
| NOTE The EXAMine switch always increments the PC regardless of the rotary switch setting, however the memory data can be displayed only if the rotary switch is set to MD.
HALT | Flipping the HALT switch down causes the main memory program to stop execution and control returns to BTS6120. The RUN LED is turned off. Flipping the HALT switch up allows the main memory program to continue, however it does not actually start the main memory program running until the CONTinue switch is pressed.
| Pressing the CONTinue switch while the HALT switch is down executes a single instruction each time the CONTinue switch is pressed. This action is equivalent to the BTS6120 TR or SI commands.
DEP | Lifting the DEPosit switch (it is "upside down" from the other spring loaded switches) will deposit the contents of the switch register into the memory location addressed by the program counter. After the data is deposited the program counter is incremented, the MEMORY ADDRESS LEDs are updated and, if the rotary switch is set to the MD position, the contents of the new location are displayed.

Table 2 - Front Panel Switches

### 3.3 ROTARY SWITCH

This four position rotary switch designates which of four possible registers are displayed on the adjacent twelve DATA LEDs.

MD | The DATA LEDs display the contents of the memory location indicated by the MEMORY ADDRESS and EMA displays.
MQ | The DATA LEDs display the contents of the Multiplier-Quotient register.

AC | The DATA LEDs display the contents of the Accumulator.
FLAGS | The DATA LEDs display the current processor flags as follows:
Bit 0 | ON if the LINK bit is set
Bit 2 | ON if an INTerrupt REQuest is asserted
Bit 4 | ON if interrupts are enabled
Bits 6..8 | Displays the current contents of the instruction field register
Bits 9..11 Displays the current contents of the data field register Table 3 - Rotary Switch Positions

### 3.4 POWER AND PANEL LOCK SWITCHES

If the Power switch, S1, and Panel Lock switch, PLOCK, are mounted on the PC board then they will be two tiny toggle switches along the lower edge of the front panel. Power is on the right and Panel Lock is on the left. Frequently these switches will be mounted off the PC board; see section 2.5.3.
The Power switch, of course, switches power on and off for the entire SBC6120/FP6120 assembly.
The Panel Lock switch will disable all front panel switches except for the switch register (SR0 .. SR11) and the rotary switch. Panel Lock has no effect on the data displayed by the LEDs.

### 3.5 DIFFERENCES BETWEEN THE FP6120 AND THE PDP-8/E

The operation of the EXAMine switch on the FP6120 is subtly different from a real PDP-8/E. A real PDP-8/E post-increments the address register. This means that on a real PDP-8/E the DATA LEDs display the contents of location (n), however at the same time the MEMORY ADDRESS LEDs show n+1! In the FP6120 the MEMORY ADDRESS and DATA displays are always synchronized; i.e. the data displayed is always the contents of the address displayed.
In a real PDP-8/E it's not possible to use the EXAMine switch to step thru a sequence of locations, find one that you want to change, load the new data into the switch register, and press DEPosit. That's because a real PDP-8/E post-increments after the EXAMine switch is pressed and the MEMORY ADDRESS displayed is actually one more than the corresponding data displayed. If you press DEPosit at this point you'll actually change the location after the one you wanted to change! The FP6120 doesn't have this problem, and you can mix the EXAMine and DEPosit switches without any unexpected consequences.
The rotary switch on the FP6120 has two fewer positions than a PDP-8/E – the missing options are BUS and STATE. Also, the FLAGS position of the FP6120 omits a few bits that are displayed on the PDP-8/E; in particular, the USER MODE, INTERRUPT INHIBIT and GREATER THAN FLAG bits are absent.
In a real PDP-8/E the BOOT switch was actually labeled SW (the “SWITCH” switch!) and was intended as a generic OMNIBUS control signal. To the best of my knowledge it was never used for any purpose other than to trigger the MI8E bootstrap loader, which is consistent with the BOOT label on the FP6120. Also, in the FP6120 it is necessary to press the BOOT switch twice before it has any effect; this is to prevent an accidental activation of this switch.⁵

5 The PDP-8/A (not the /E!) Programmer’s Console has a button labeled “BOOT” which has exactly the same effect as the SW switch on the 8/E. In the case of the PDP-8/A, however, the BOOT button also must be pressed twice before it has any effect.

The PDP-8/E front panel also had a SINGle STEP switch which would execute a single memory cycle. The SBC6120 has no equivalent function, however note that the PDP-8/E SINGle STEP switch did not execute a single instruction! In the PDP-8/E a single instruction was executed by leaving the HALT switch down while pressing CONTinue, which is exactly the same method used by the SBC6120/FP6120.
Because of the missing key switch and SINGle STEP switch, the switches on the FP6120 have been re-arranged slightly to keep the panel “balanced”. In particular, the LOAD ADDRess and EXTendeD ADDRess LOAD switches have been moved from the right side of the switch register to the left.

A.

# PARTS

# LIST

REFERENCE | MANUFACTURER | PART | SUPPLIER | STOCK | QTY | DESCRIPTION
DESIGNATOR | | NUMBER | | NUMBER
U1, U2 | | 74HC373 | JDR | | 2 | Octal D Tri-State Latch
U3, U4 | | 74HC174 | JDR | | 2 | Hex D flip-flop
U5, U6, U9, U10 | | 74HC366 or 368 | JDR | | 4 | Hex Tri-State Inverting Buffer (either the 74HC366 or 74HC368 may be used!)
U7 | Atmel | ATF22V10B15PC Arrow | 1 | CMOS PLD (Flash)
U8 | | 7555 | JDR | | 1 | CMOS Timer (may be TLC555)
U11 | | 74HC74 | JDR | | 1 | Dual D flip-flop
U12 | | 74HC05 | JDR | | 1 | Hex Open Drain Inverting Buffer
U13 | Atmel | ATF16V8B15PC | Arrow | | 1 | CMOS PLD (Flash)
REG1 | TI | PT78HT205H | Digikey | PT78HT205H | 1 | 5V 2A Switching Regulator 3 pin SIP Horizontal (Can use PT78HT305H for extra current)
D1 | | 1N5820 | Digikey | 1N5820GICT | 1 | Schottky Diode 3A 20V DO-201
D2 | | 1N5339 | Digikey | 1N5339BMSCT | 1 | Zener Diode 5.6V 5% 5.0W T-18
F1 | Littelfuse | 473.003 | Digikey | F1204CT | 1 | 3A picofuse
R1 | | | Digikey | BC10.0KXCT | 1 | 10.0K 1% 1/8W carbon resistor
R2 | | | Digikey | BC17.4KYCT | 1 | 17.4K 1% 1/8W carbon resistor
R3, R4 | | | | | 2 | 10K 5% 1/8W carbon resistor
RP1, RP2 | | | Digikey | 4310R-1-561 | 2 | 560 ohm 10 Pin SIP Resistor
RP3, RP4 | | | Digikey | 4308R-1-561 | 2 | 560 ohm 8 Pin SIP Resistor
RP5, RP6 | | | Digikey | 4308R-1-472 | 2 | 4.7K ohm 8 Pin SIP Resistor
RP7 | | | Digikey | 4310R-1-472 | 1 | 4.7K ohm 10 pin SIP Resistor
RP8 | | | Digikey | 4306R-1-472 | 1 | 4.7K ohm 6 pin SIP Resistor
C1 | | | Digikey | 399-1429 | 1 | 1uF 25V radial lead tantalum capacitor
C2, C7 | | | Digikey | 399-1906 | 2 | Unused (0.01uF 10VDC Mono ceramic capacitor)
C8 | | | Digikey | | 1 | 100uf 25V radial lead aluminum electrolytic
C9, C10, C11, C12, C13, C14, C15, C16, C18, C19,
C20, C21 | | | | | 12 | 0.1uF 50V mono ceramic capacitor (0.1" lead spacing)
J1 | Comm Con | 1184-50G2 | STG | 1184-50G2 | 1 | 50 pin Male / Female Stackable connector
J2 | Comm Con | 1185-50G | STG | 1185-50G | 1 | 50 pin Female connector

REFERENCE | MANUFACTURER | PART | SUPPLIER | STOCK | QTY | DESCRIPTION
DESIGNATOR | | NUMBER | | NUMBER
J3 | CUI Stack | PJ-102AH | Digikey | PJ-102AH | 1 | PCB Mount Jack 2.1 x 5.5mm High Current
J4 | | | | | | 2 pin male header (see section 2.5.4)
J5 | | | | | | 2 pin female header (see section 2.5.4)
JP1, JP2 | | | Jameco | SMH02 | 2 | 2 pin header (Jumper)
FB1, FB2 | | | | | 2 | Ferrite Bead (0.400" Lead spacing)
S1, PLOCK | C&K | T101MH9ABE | Digikey | CKN1067 | 2 | SPDT Tiny Toggle Switch, PCB Mount Right Angle
| C&K | 7101J60V6BE1 | | | 13 | SPDT PCB mount paddle switch, ON-NONE-ON
| C&K | 7108J60V6BE1 | | | 7 | SPDT PCB mount paddle switch, ON-NONE-MOM
| Lorlin | 10WA346 | Mouser | 10WA346 | 1 | 3 pole 4 position PCB mount rotary switch
| Kingbright | L53ID | Mouser | 604-L53ID | 28 | Red LED, T1-3/4 high efficiency
| Keystone | 8555 | Digikey | 8555K | 1 | Knob, round 0.7" diameter
| Keystone | 1560A | Mouser | 534-1560A | 20 | 4-40 solder in stand offs, 0.125" high, 0.250" diameter
Spare Time Gizmos FP6120-1D | 1 | FP6120 PC board, revision E
Spare Time Gizmos FP6120-FPK | 1 | FP6120 Faceplate Kit
Spare Time Gizmos FP6120-LBK | 1 | FP6120 LED Aligner/Spacer Bar Kit
| | | | | 1 | 24 Pin Machined Pin DIP Socket (0.300")
| | | | | 3 | 20 Pin Machined Pin DIP Socket
| | | | | 6 | 16 Pin Machined Pin DIP Socket
| | | | | 2 | 14 Pin Machined Pin DIP Socket
| | | | | 1 | 8 Pin Machined Pin DIP Socket
| | | | | 5 | #4-40 1/2" round nylon M/F spacers
| | | | | 5 | #4-40 1/4" nylon screws
Table 4 – FP6120 Parts List

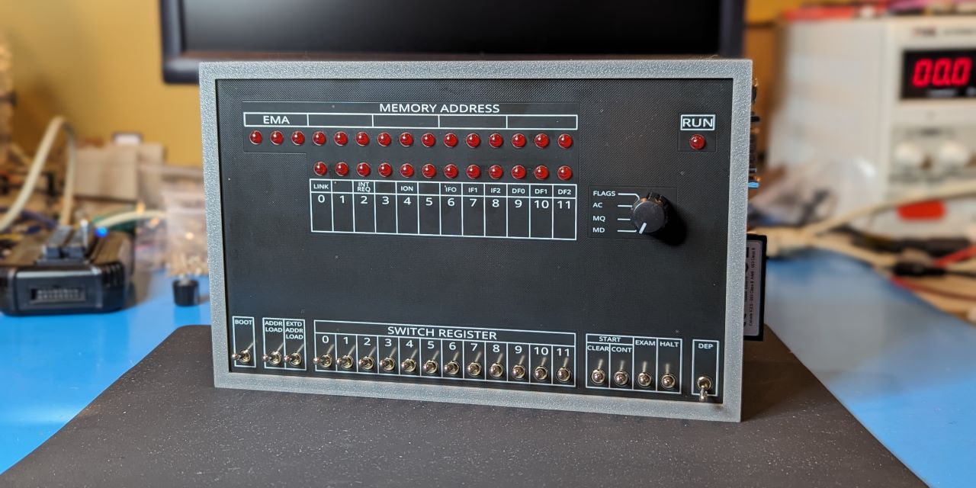
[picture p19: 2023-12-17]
docs/social.jpg

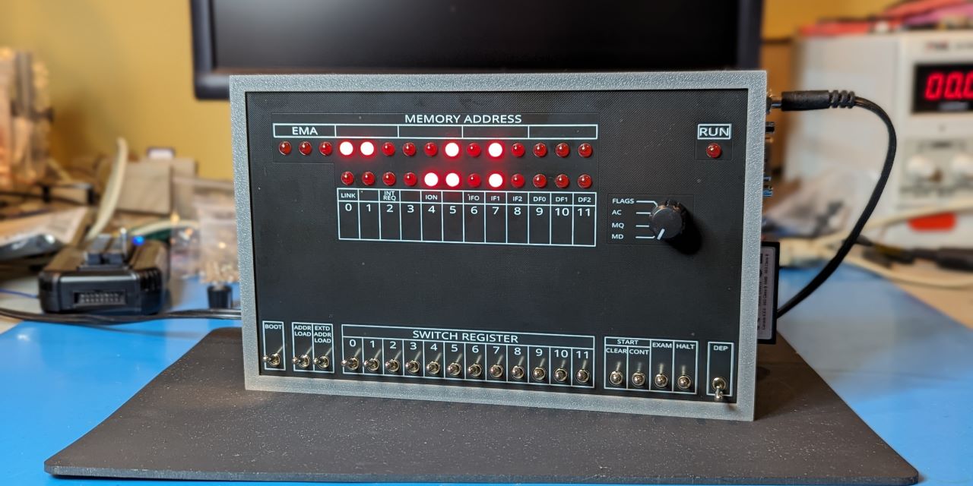
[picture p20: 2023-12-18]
docs/social-on.jpg

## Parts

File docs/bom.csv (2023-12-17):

# | Reference | Qty | Value | Footprint | DNP
1 | C1 | 1 | 0.01UF | Capacitor_THT:C_Disc_D5.1mm_W3.2mm_P5.00mm
2 | C2, C3, C4, C5, C7, C8, C9, C10, C11, C12, C13, C14, C15 | 13 | 100NF | Capacitor_THT:C_Disc_D5.1mm_W3.2mm_P5.00mm
3 | C6 | 1 | 1UF 10V | Capacitor_THT:C_Disc_D5.1mm_W3.2mm_P5.00mm
4 | C16 | 1 | 470uF 10V | Capacitor_THT:CP_Radial_D8.0mm_P3.50mm
5 | D1 | 1 | EMA0 | LED_THT:LED_D5.0mm
6 | D2 | 1 | EMA1 | LED_THT:LED_D5.0mm
7 | D3 | 1 | EMA2 | LED_THT:LED_D5.0mm
8 | D4 | 1 | MA0 | LED_THT:LED_D5.0mm
9 | D5 | 1 | MA1 | LED_THT:LED_D5.0mm
10 | D6 | 1 | MA2 | LED_THT:LED_D5.0mm
11 | D7 | 1 | MA3 | LED_THT:LED_D5.0mm
12 | D8 | 1 | MA4 | LED_THT:LED_D5.0mm
13 | D9 | 1 | MA5 | LED_THT:LED_D5.0mm
14 | D10 | 1 | MA6 | LED_THT:LED_D5.0mm
15 | D11 | 1 | MA7 | LED_THT:LED_D5.0mm
16 | D12 | 1 | MA8 | LED_THT:LED_D5.0mm
17 | D13 | 1 | MA9 | LED_THT:LED_D5.0mm
18 | D14 | 1 | MA10 | LED_THT:LED_D5.0mm
19 | D15 | 1 | MA11 | LED_THT:LED_D5.0mm
20 | D16 | 1 | MD0 | LED_THT:LED_D5.0mm
21 | D17 | 1 | MD1 | LED_THT:LED_D5.0mm
22 | D18 | 1 | MD2 | LED_THT:LED_D5.0mm
23 | D19 | 1 | MD3 | LED_THT:LED_D5.0mm
24 | D20 | 1 | MD4 | LED_THT:LED_D5.0mm
25 | D21 | 1 | MD5 | LED_THT:LED_D5.0mm
26 | D22 | 1 | MD6 | LED_THT:LED_D5.0mm
27 | D23 | 1 | MD7 | LED_THT:LED_D5.0mm
28 | D24 | 1 | MD8 | LED_THT:LED_D5.0mm
29 | D25 | 1 | MD9 | LED_THT:LED_D5.0mm
30 | D26 | 1 | MD10 | LED_THT:LED_D5.0mm
31 | D27 | 1 | MD11 | LED_THT:LED_D5.0mm
32 | D28 | 1 | RUN | LED_THT:LED_D5.0mm
33 | H1, H2, H3, H4, H5, H6, H7, H8, H9, H10, H11, H12 | 12 | MountingHole | Tersteeg:MountingHole_3.2mm_M3_Bare
34 | J1 | 1 | Conn_02x25_Odd_Even | Connector_PinHeader_2.54mm:PinHeader_2x25_P2.54mm_Vertical
35 | J2 | 1 | SBC CPREQ | Connector_PinHeader_2.54mm:PinHeader_1x02_P2.54mm_Vertical
36 | R1 | 1 | 10.0K 1% | Resistor_THT:R_Axial_DIN0207_L6.3mm_D2.5mm_P7.62mm_Horizontal
37 | R2 | 1 | 17.4K 1% | Resistor_THT:R_Axial_DIN0207_L6.3mm_D2.5mm_P7.62mm_Horizontal
38 | R3, R4 | 2 | 10K | Resistor_THT:R_Axial_DIN0207_L6.3mm_D2.5mm_P7.62mm_Horizontal
39 | RN1, RN2, RN3, RN4 | 4 | 560R | Resistor_THT:R_Array_SIP9
40 | RN5, RN6, RN8 | 3 | 4.7K | Resistor_THT:R_Array_SIP7
41 | RN7 | 1 | 4.7K | Resistor_THT:R_Array_SIP5
42 | RN9 | 1 | 4.7K | Resistor_THT:R_Array_SIP6
43 | SW1 | 1 | SR0 | Tersteeg:Miniature Toggle Switch SPDT - Oval Holes
44 | SW2 | 1 | SR1 | Tersteeg:Miniature Toggle Switch SPDT - Oval Holes
45 | SW3 | 1 | SR2 | Tersteeg:Miniature Toggle Switch SPDT - Oval Holes
46 | SW4 | 1 | SR3 | Tersteeg:Miniature Toggle Switch SPDT - Oval Holes
47 | SW5 | 1 | SR4 | Tersteeg:Miniature Toggle Switch SPDT - Oval Holes
48 | SW6 | 1 | SR5 | Tersteeg:Miniature Toggle Switch SPDT - Oval Holes
49 | SW7 | 1 | SR6 | Tersteeg:Miniature Toggle Switch SPDT - Oval Holes
50 | SW8 | 1 | SR7 | Tersteeg:Miniature Toggle Switch SPDT - Oval Holes
51 | SW9 | 1 | SR8 | Tersteeg:Miniature Toggle Switch SPDT - Oval Holes
52 | SW10 | 1 | SR9 | Tersteeg:Miniature Toggle Switch SPDT - Oval Holes
53 | SW11 | 1 | SR10 | Tersteeg:Miniature Toggle Switch SPDT - Oval Holes
54 | SW12 | 1 | SR11 | Tersteeg:Miniature Toggle Switch SPDT - Oval Holes
55 | SW13 | 1 | BOOT | Tersteeg:Miniature Toggle Switch SPDT - Oval Holes
56 | SW14 | 1 | LA | Tersteeg:Miniature Toggle Switch SPDT - Oval Holes
57 | SW15 | 1 | LXA | Tersteeg:Miniature Toggle Switch SPDT - Oval Holes
58 | SW16 | 1 | CLEAR | Tersteeg:Miniature Toggle Switch SPDT - Oval Holes
59 | SW17 | 1 | CONT | Tersteeg:Miniature Toggle Switch SPDT - Oval Holes
60 | SW18 | 1 | EXAM | Tersteeg:Miniature Toggle Switch SPDT - Oval Holes
61 | SW19 | 1 | DEP | Tersteeg:Miniature Toggle Switch SPDT - Oval Holes
62 | SW20 | 1 | HALT | Tersteeg:Miniature Toggle Switch SPDT - Oval Holes
63 | SW21 | 1 | RM104772BCB | RM104772BCB-SnapEDA:RM104772BCB
64 | SW22 | 1 | PLOCK | Connector_PinHeader_2.54mm:PinHeader_1x03_P2.54mm_Vertical
65 | SW23 | 1 | 30HZ | Connector_PinHeader_2.54mm:PinHeader_1x03_P2.54mm_Vertical
66 | SW24 | 1 | ENABLE CONSOLE SLU BREAK REQ | Connector_PinHeader_2.54mm:PinHeader_1x03_P2.54mm_Vertical
67 | U1, U2 | 2 | 74HC373 | Package_DIP:DIP-20_W7.62mm_Socket
68 | U3, U4 | 2 | 74HC174 | Package_DIP:DIP-16_W7.62mm_Socket
69 | U5, U6, U9, U10 | 4 | 74HC366 | Package_DIP:DIP-16_W7.62mm_Socket
70 | U7 | 1 | ATF22V10 | Package_DIP:DIP-24_W7.62mm_Socket
71 | U8 | 1 | 7555 | Package_DIP:DIP-8_W7.62mm_Socket
72 | U11 | 1 | 74HC74 | Package_DIP:DIP-14_W7.62mm_Socket
73 | U12 | 1 | 74HC05 | Package_DIP:DIP-14_W7.62mm_Socket
74 | U13 | 1 | ATF16V8 | Package_DIP:DIP-20_W7.62mm_Socket

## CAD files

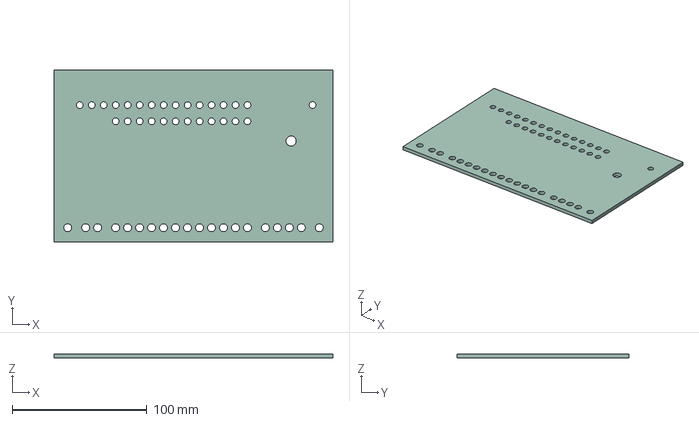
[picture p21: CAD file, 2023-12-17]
3D/STEP/sbc6120-rbc-front-dress-panel.step
207.0 x 127.6 x 3.16 mm

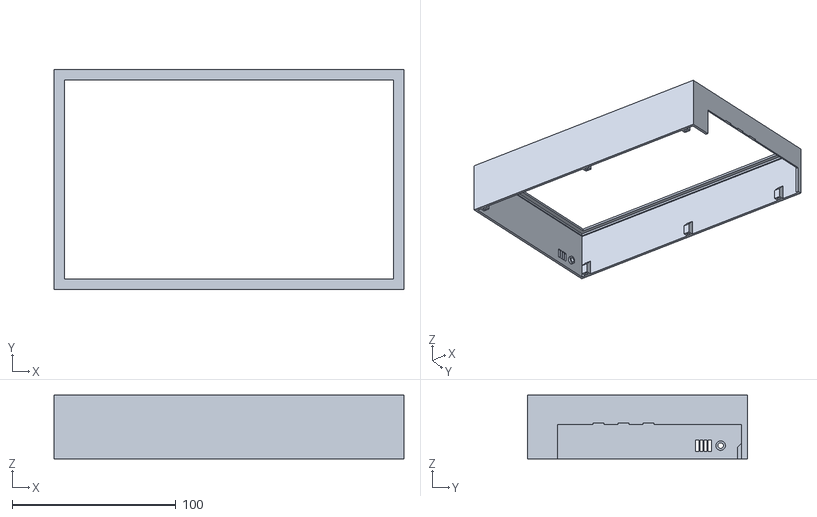
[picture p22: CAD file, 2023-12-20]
3D/STL/Top Case.stl
213.6 x 134.2 x 39.0

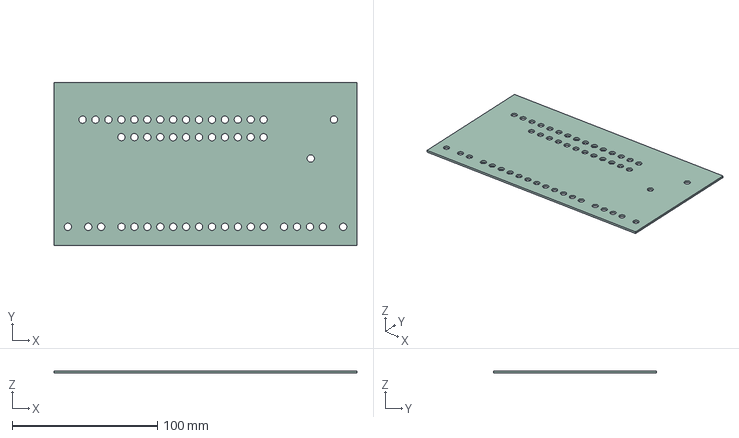
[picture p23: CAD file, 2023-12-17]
prototypes/sbc6120-rbc-front-dress-panel-submini/sbc6120-rbc-front-dress-panel-submini.step
208.3 x 111.8 x 1.58 mm

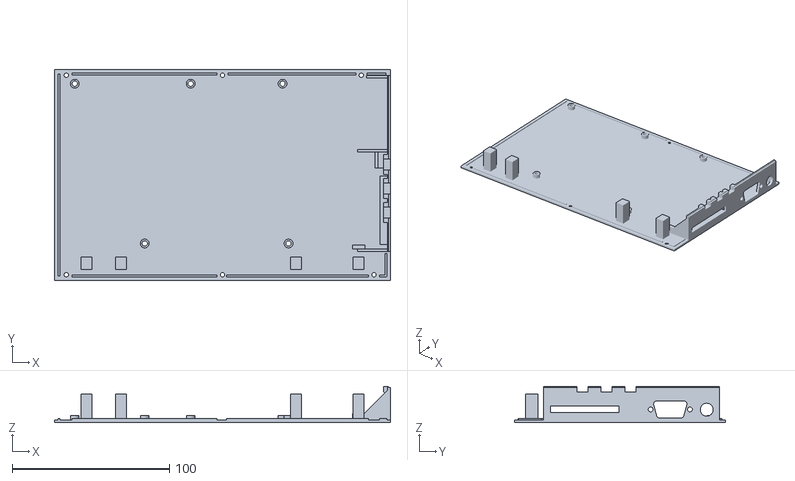
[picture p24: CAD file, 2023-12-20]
3D/STL/Bottom Plate - CF-IDE40.stl
213.6 x 134.2 x 23.2

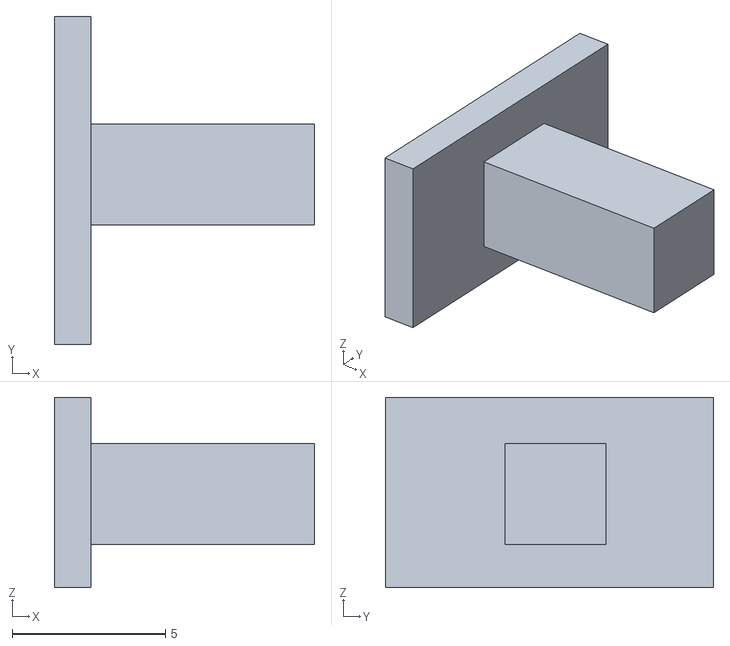
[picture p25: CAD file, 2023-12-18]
3D/STL/Slide Switch.stl
8.49 x 10.7 x 6.20

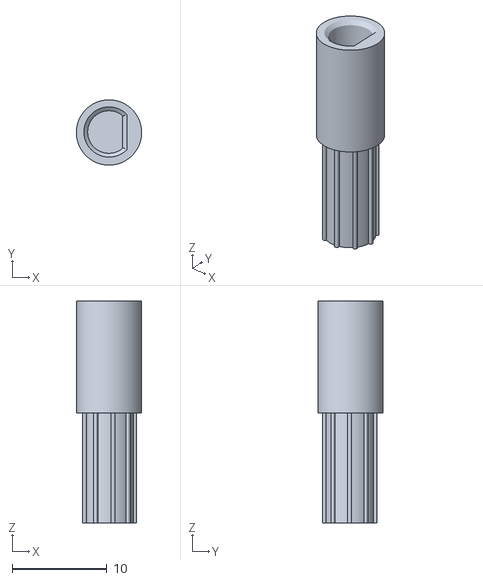
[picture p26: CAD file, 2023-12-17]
3D/STL/Rotary Knob Adapter.stl
6.90 x 6.90 x 23.4

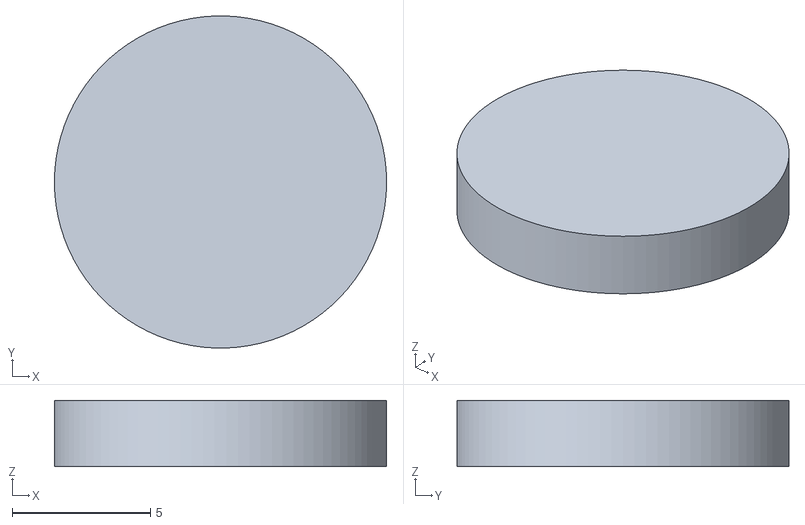
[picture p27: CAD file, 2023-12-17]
3D/STL/2.4mm LED Spacer.stl
12.0 x 12.0 x 2.40

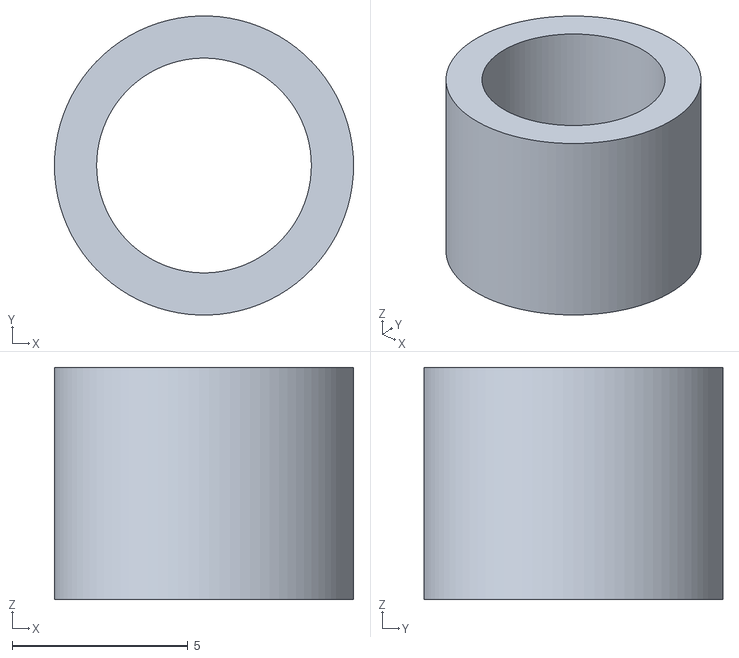
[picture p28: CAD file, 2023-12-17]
3D/STL/Switch Spacer.stl
8.50 x 8.49 x 6.60

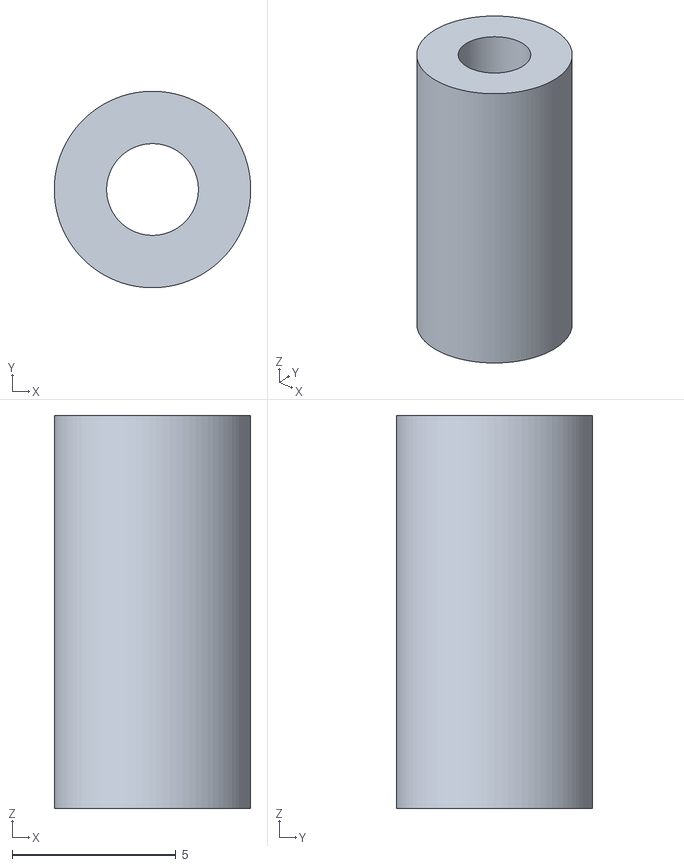
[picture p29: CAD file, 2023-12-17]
3D/STL/M3 x 12mm Standoff.stl
6.00 x 6.00 x 12.0

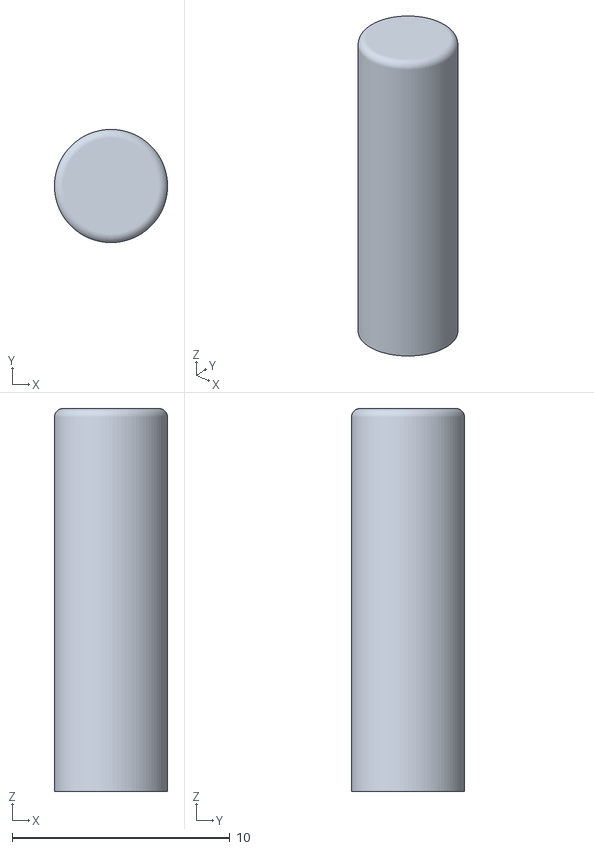
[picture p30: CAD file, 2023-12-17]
3D/STL/M3 x 17.6mm Standoff.stl
5.20 x 5.20 x 17.6

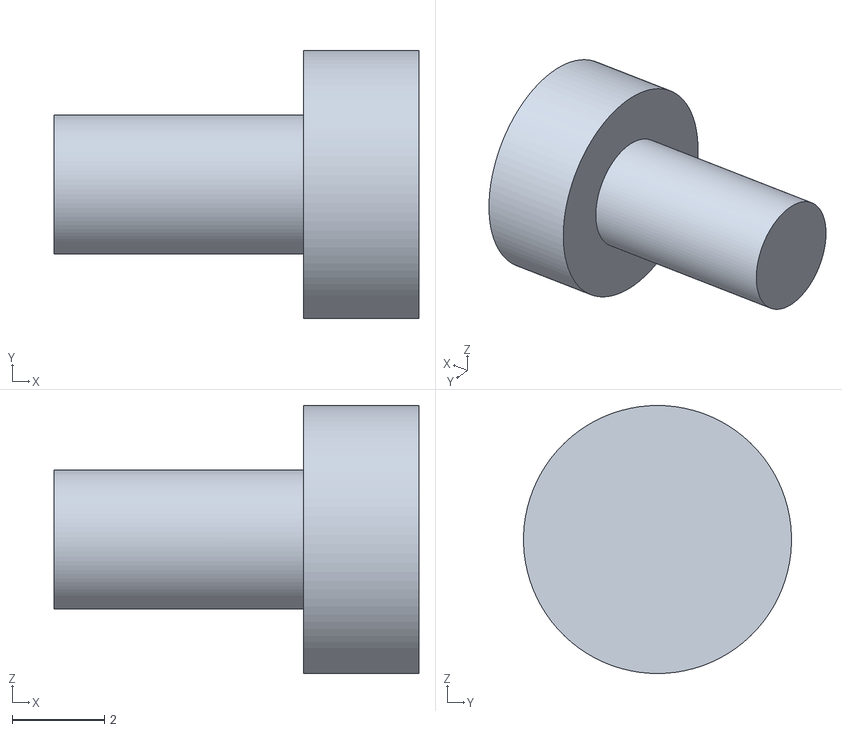
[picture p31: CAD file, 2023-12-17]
3D/STL/Reset Button.stl
7.90 x 5.80 x 5.80

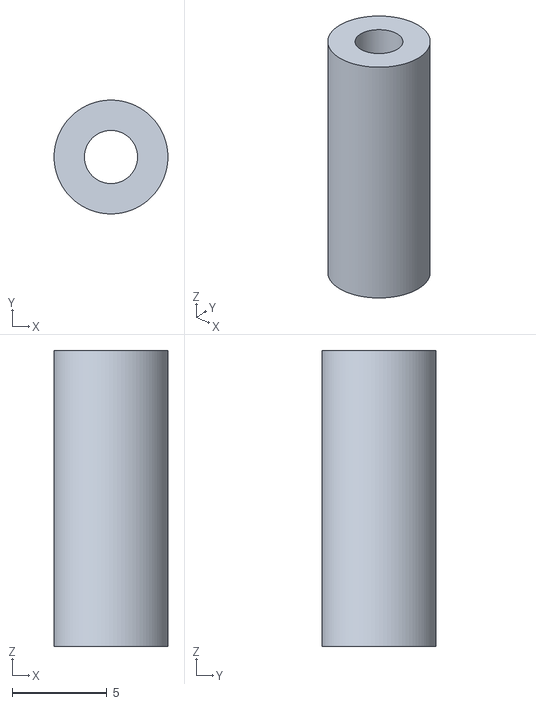
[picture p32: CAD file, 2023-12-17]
3D/STL/M3 x 15.6mm Standoff.stl
6.00 x 6.00 x 15.6

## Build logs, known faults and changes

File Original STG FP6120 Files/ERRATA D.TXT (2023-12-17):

1) Label all the mounting holes in the silk screen.

2) More clearance around the mounting holes between MA2-3-4.

3) Use standard 4-40 holes for the disk drive.

4) front and back soldermasks are exchanged.

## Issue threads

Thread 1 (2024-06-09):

Missing part in DesignSpark Mechanical project file

thunter6600, 2024-06-09:
The DesignSpark Mechanical project file (“SBC6120-RBC Front Panel Case.rsdocx”) in your sbc6120-mini-front-panel GIThub repository has only the unused “Knob”, but not the “Rotary Knob Adapter” design. The “Rotary Knob Adapter” STL is there, but not in the “.rsdocx”.

I suspect you did the “Rotary Knob Adapter” as a separate “.rxdocx” project and then created the STL from it which is in your GIThub repository.

Could you please make the “.rxdocx” for the “Rotary Knob Adapter” available?

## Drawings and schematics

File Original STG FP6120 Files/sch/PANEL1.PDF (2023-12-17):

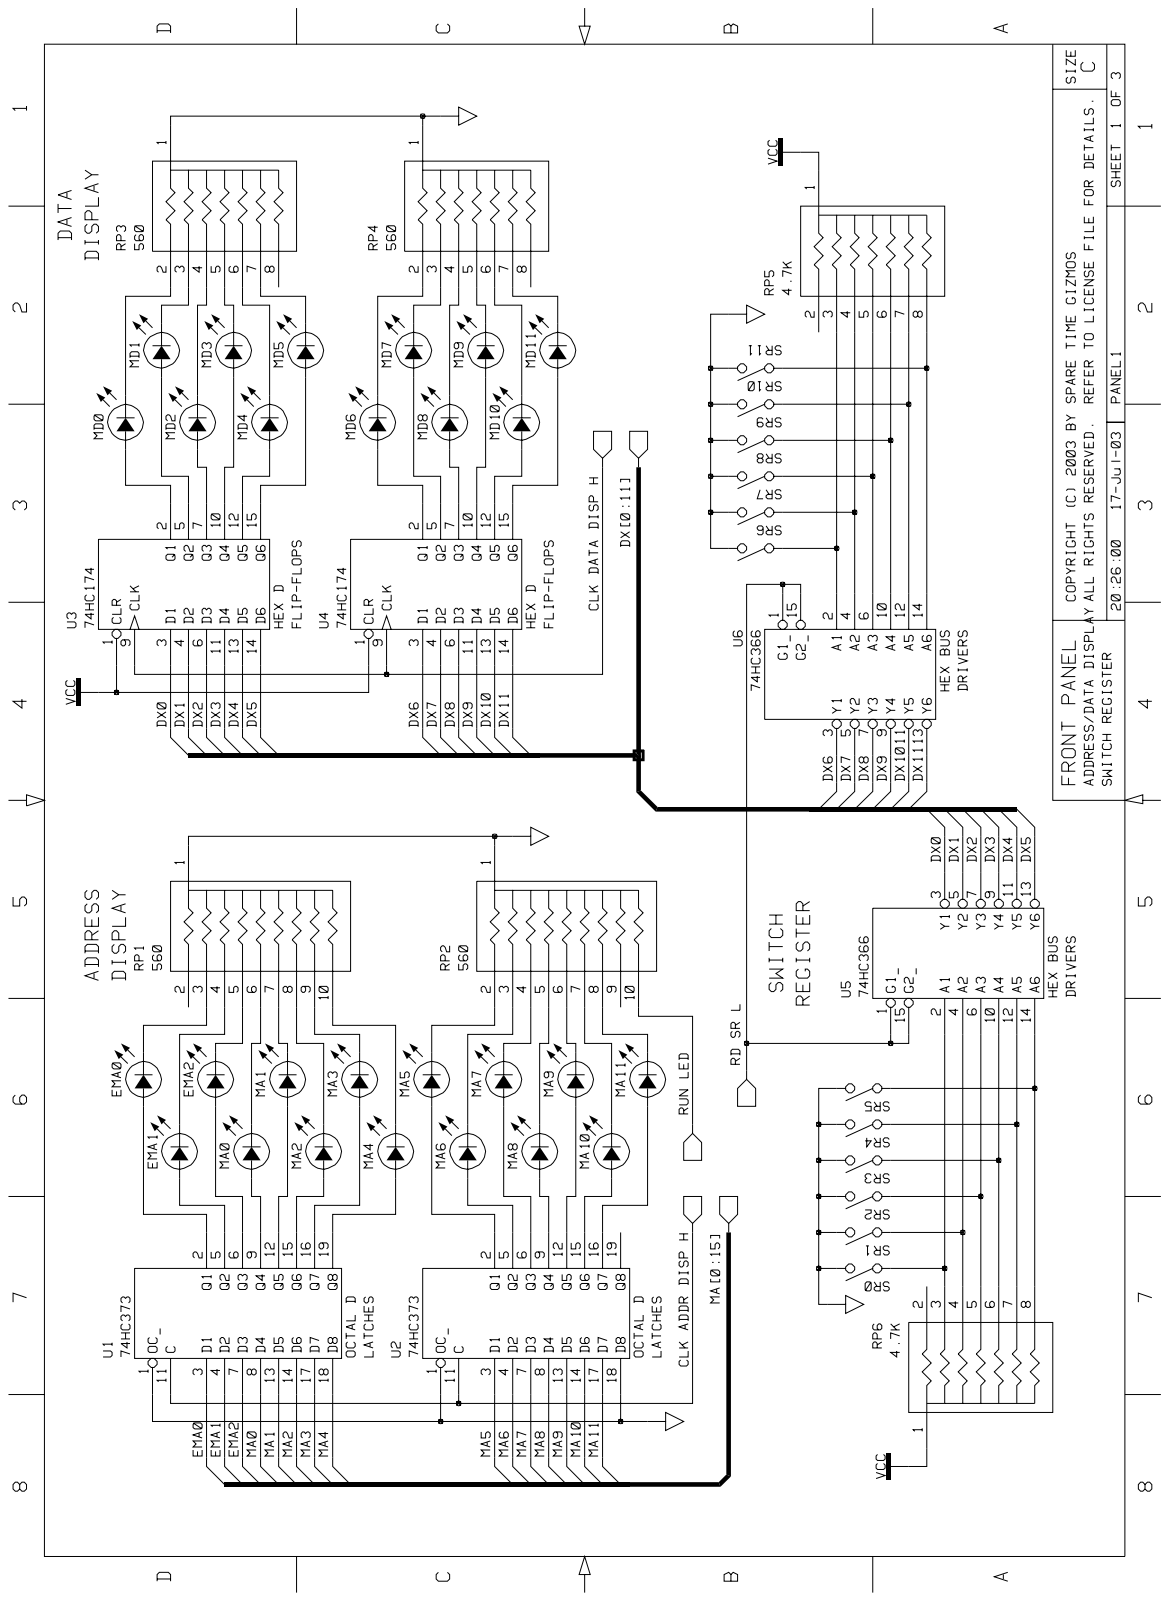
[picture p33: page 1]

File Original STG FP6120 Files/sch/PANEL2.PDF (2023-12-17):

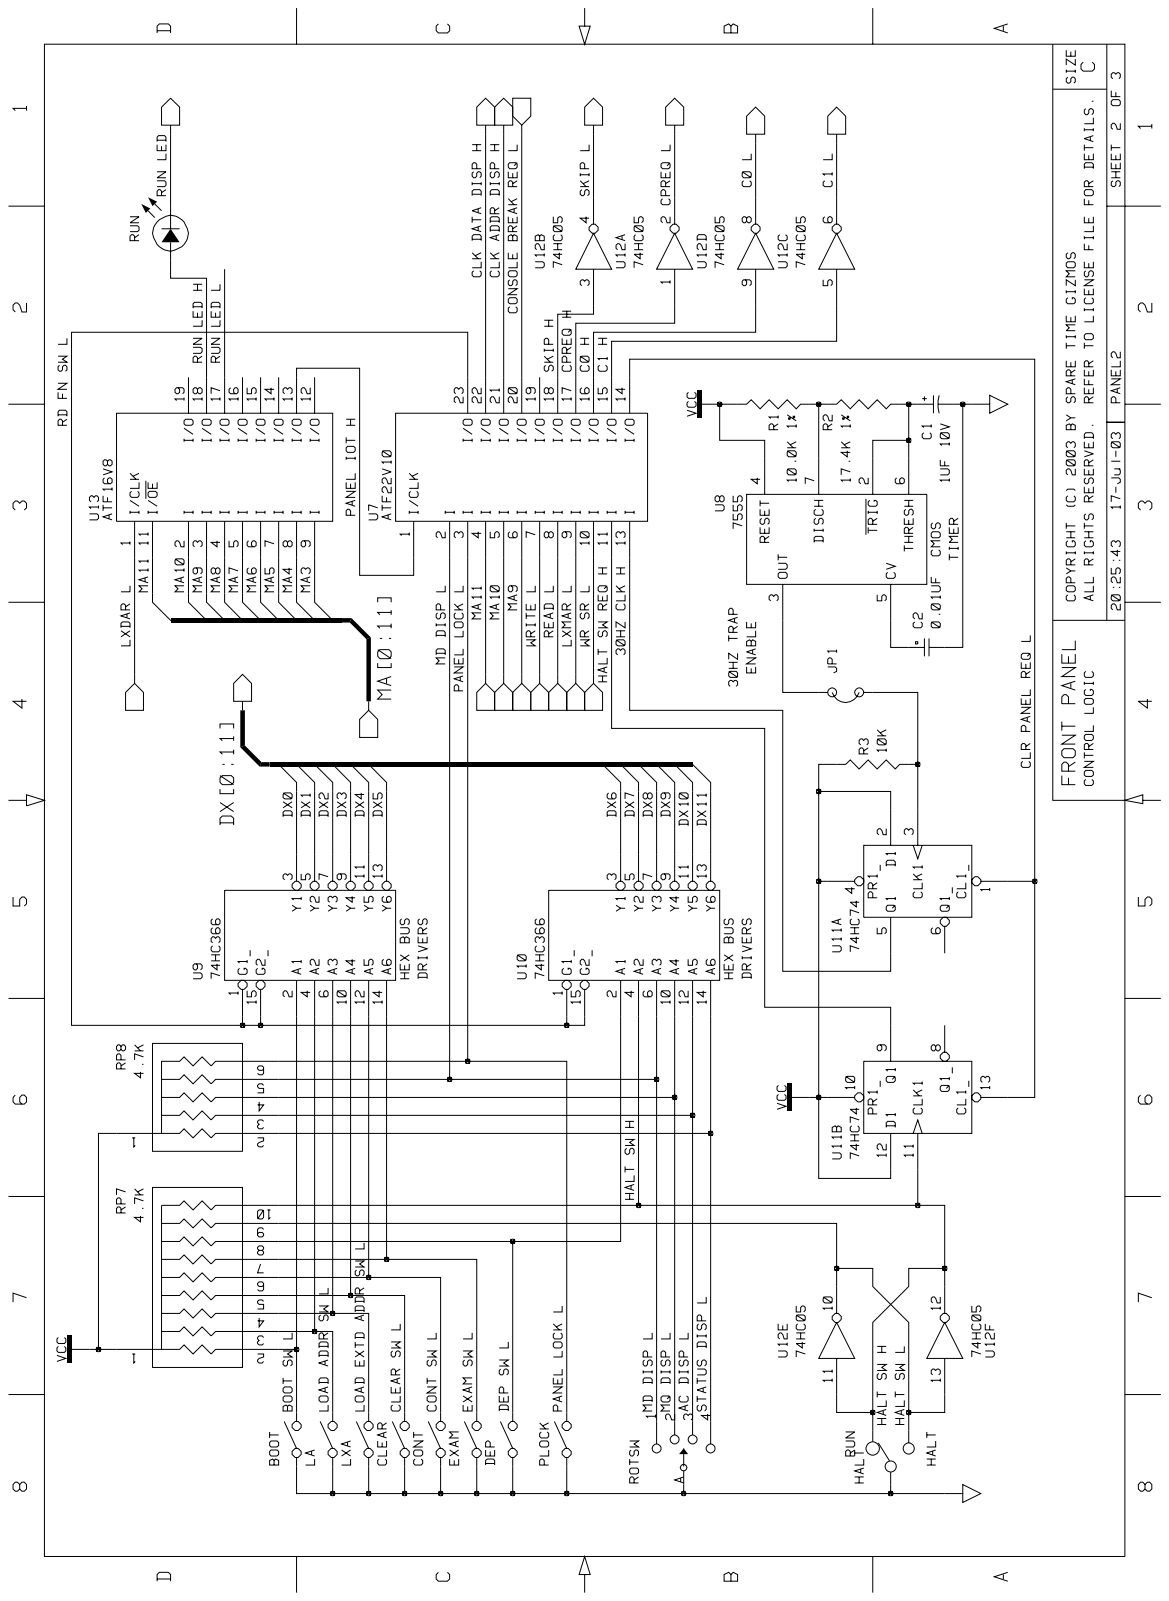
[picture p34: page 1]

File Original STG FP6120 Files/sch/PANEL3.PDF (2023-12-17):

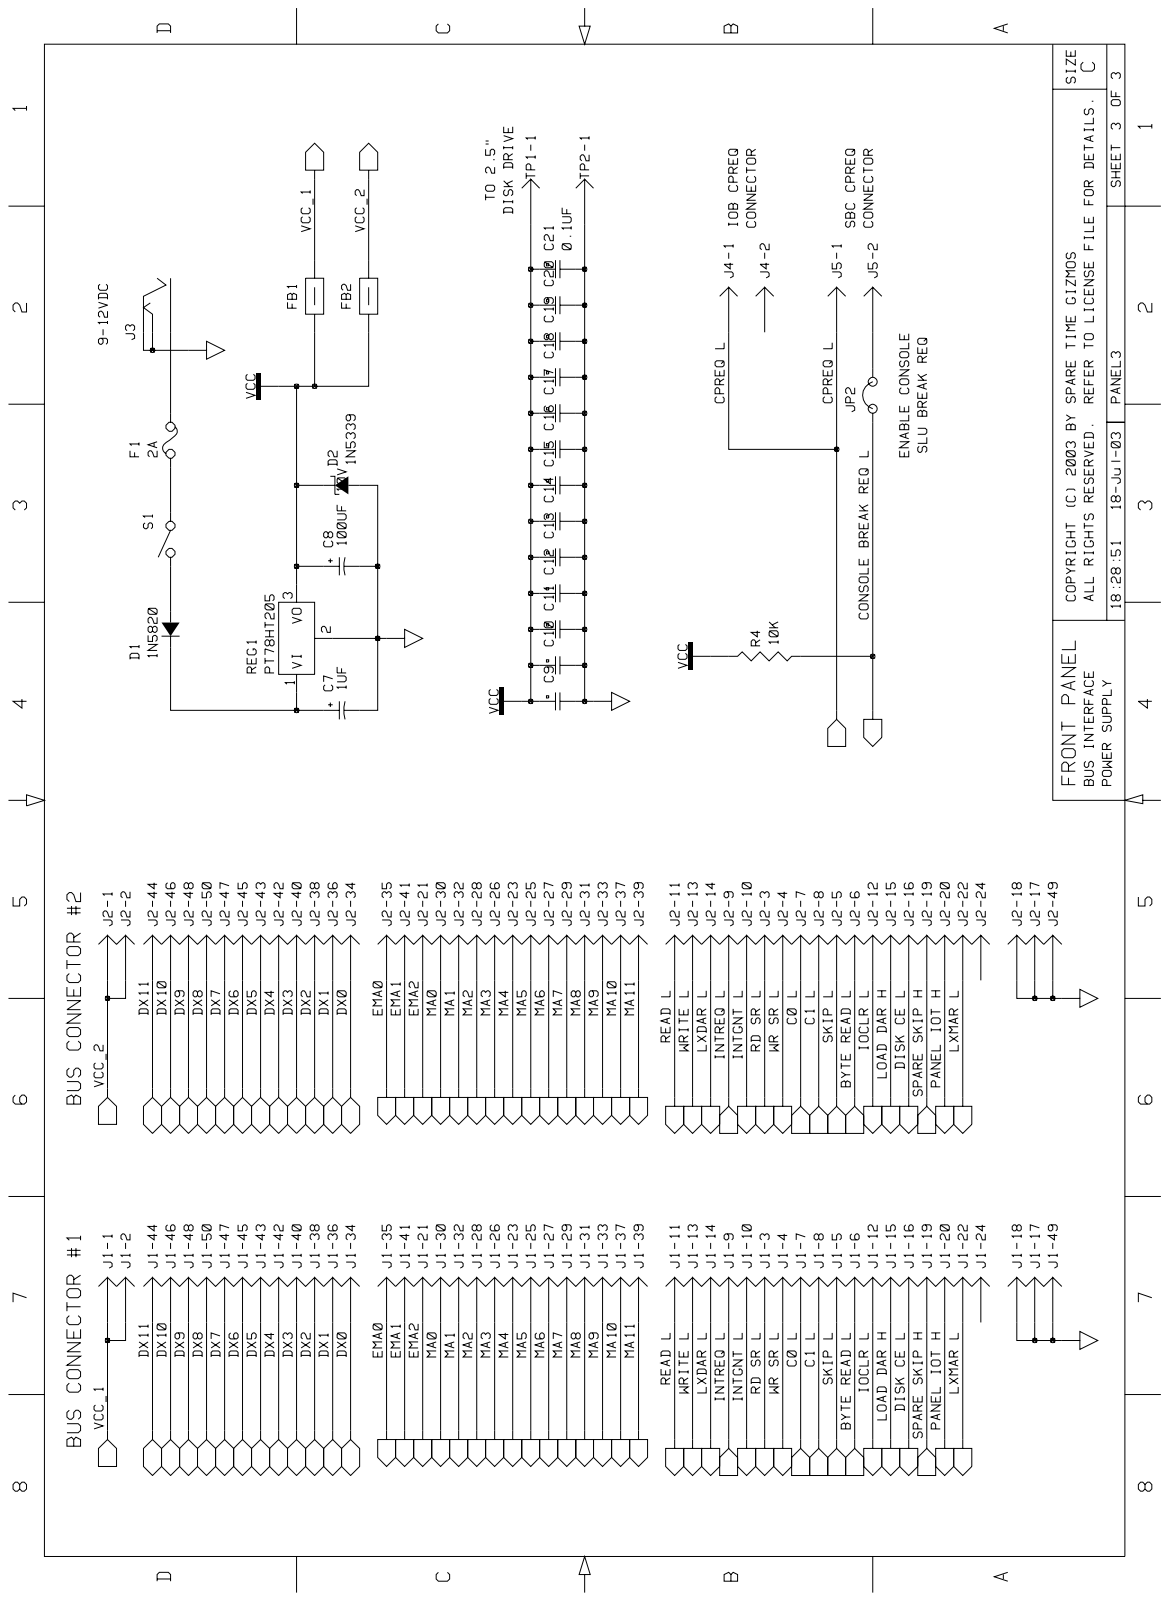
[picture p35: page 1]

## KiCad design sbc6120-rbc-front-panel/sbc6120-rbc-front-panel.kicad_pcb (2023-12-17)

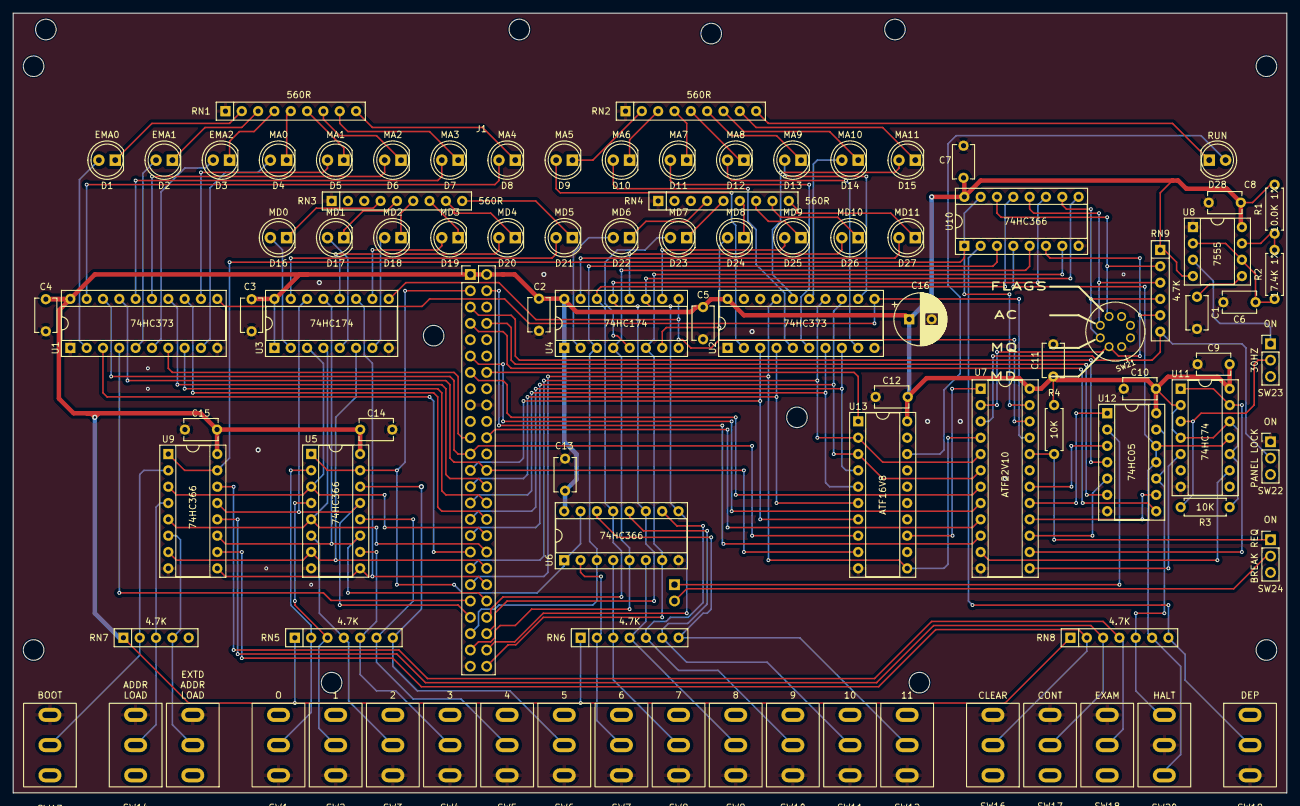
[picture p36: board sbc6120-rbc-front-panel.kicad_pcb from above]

Board: 2 copper layers, 198.1 x 121.3 mm, 108 parts (1 on the bottom side), 139 nets.

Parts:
C1: 0.01UF; C_Disc_D5.1mm_W3.2mm_P5.00mm
C2, C3, C4, C5, C7, C8, C9, C10, C11, C12, C13, C14, C15: 100NF; C_Disc_D5.1mm_W3.2mm_P5.00mm
C6: 1UF 10V; C_Disc_D5.1mm_W3.2mm_P5.00mm
C16: 470uF 10V; CP_Radial_D8.0mm_P3.50mm
D1: EMA0; LED_D5.0mm
D2: EMA1; LED_D5.0mm
D3: EMA2; LED_D5.0mm
D4: MA0; LED_D5.0mm
D5: MA1; LED_D5.0mm
D6: MA2; LED_D5.0mm
D7: MA3; LED_D5.0mm
D8: MA4; LED_D5.0mm
D9: MA5; LED_D5.0mm
D10: MA6; LED_D5.0mm
D11: MA7; LED_D5.0mm
D12: MA8; LED_D5.0mm
D13: MA9; LED_D5.0mm
D14: MA10; LED_D5.0mm
D15: MA11; LED_D5.0mm
D16: MD0; LED_D5.0mm
D17: MD1; LED_D5.0mm
D18: MD2; LED_D5.0mm
D19: MD3; LED_D5.0mm
D20: MD4; LED_D5.0mm
D21: MD5; LED_D5.0mm
D22: MD6; LED_D5.0mm
D23: MD7; LED_D5.0mm
D24: MD8; LED_D5.0mm
D25: MD9; LED_D5.0mm
D26: MD10; LED_D5.0mm
D27: MD11; LED_D5.0mm
D28: RUN; LED_D5.0mm
H1, H2, H3, H4, H5, H6, H7, H8, H9, H10, H11, H12: MountingHole; MountingHole_3.2mm_M3_Bare
J1: Conn_02x25_Odd_Even; PinHeader_2x25_P2.54mm_Vertical
J2: SBC CPREQ; PinHeader_1x02_P2.54mm_Vertical
R1: 10.0K 1%; R_Axial_DIN0207_L6.3mm_D2.5mm_P7.62mm_Horizontal
R2: 17.4K 1%; R_Axial_DIN0207_L6.3mm_D2.5mm_P7.62mm_Horizontal
R3, R4: 10K; R_Axial_DIN0207_L6.3mm_D2.5mm_P7.62mm_Horizontal
RN1, RN2, RN3, RN4: 560R; R_Array_SIP9
RN5, RN6, RN8: 4.7K; R_Array_SIP7
RN7: 4.7K; R_Array_SIP5
RN9: 4.7K; R_Array_SIP6
SW1: SR0; Miniature Toggle Switch SPDT - Oval Holes
SW2: SR1; Miniature Toggle Switch SPDT - Oval Holes
SW3: SR2; Miniature Toggle Switch SPDT - Oval Holes
SW4: SR3; Miniature Toggle Switch SPDT - Oval Holes
SW5: SR4; Miniature Toggle Switch SPDT - Oval Holes
SW6: SR5; Miniature Toggle Switch SPDT - Oval Holes
SW7: SR6; Miniature Toggle Switch SPDT - Oval Holes
SW8: SR7; Miniature Toggle Switch SPDT - Oval Holes
SW9: SR8; Miniature Toggle Switch SPDT - Oval Holes
SW10: SR9; Miniature Toggle Switch SPDT - Oval Holes
SW11: SR10; Miniature Toggle Switch SPDT - Oval Holes
SW12: SR11; Miniature Toggle Switch SPDT - Oval Holes
SW13: BOOT; Miniature Toggle Switch SPDT - Oval Holes
SW14: LA; Miniature Toggle Switch SPDT - Oval Holes
SW15: LXA; Miniature Toggle Switch SPDT - Oval Holes
SW16: CLEAR; Miniature Toggle Switch SPDT - Oval Holes
SW17: CONT; Miniature Toggle Switch SPDT - Oval Holes
SW18: EXAM; Miniature Toggle Switch SPDT - Oval Holes
SW19: DEP; Miniature Toggle Switch SPDT - Oval Holes
SW20: HALT; Miniature Toggle Switch SPDT - Oval Holes
SW21: SP4T; RM104772BCB
SW22: PLOCK; PinHeader_1x03_P2.54mm_Vertical
SW23: 30HZ; PinHeader_1x03_P2.54mm_Vertical
SW24: ENABLE CONSOLE SLU BREAK REQ; PinHeader_1x03_P2.54mm_Vertical
U1, U2: 74HC373; DIP-20_W7.62mm_Socket
U3, U4: 74HC174; DIP-16_W7.62mm_Socket
U5, U6, U9, U10: 74HC366; DIP-16_W7.62mm_Socket
U7: ATF22V10; DIP-24_W7.62mm_Socket
U8: 7555; DIP-8_W7.62mm_Socket
U11: 74HC74; DIP-14_W7.62mm_Socket
U12: 74HC05; DIP-14_W7.62mm_Socket
U13: ATF16V8; DIP-20_W7.62mm_Socket

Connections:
/control-logic/HALT: RN8.5 (R4), SW20.3 (C), U12.10, U12.13
/control-logic/RUN: RN8.6 (R5), SW20.1 (A), U10.4 (I2), U11.11 (C), U12.11, U12.12
/control-logic/RUN LED H: D28.2 (A), U13.18 (IO2)
/control-logic/~AC DISP: RN9.3 (R2), SW21.3, U10.12 (I5)
/control-logic/~BOOT SW: RN7.2 (R1), SW13.2 (B), U9.2 (I1)
/control-logic/~CLEAR SW: RN8.2 (R1), SW16.2 (B), U9.10 (I4)
/control-logic/~CONSOLE BREAK REQ: R4.2, SW24.1 (A), U7.20 (IO4)
/control-logic/~CONT SW: RN8.3 (R2), SW17.2 (B), U9.12 (I5)
/control-logic/~CPREQ: J2.1, U12.2
/control-logic/~DEP SW: RN8.7 (R6), SW19.2 (B), U10.2 (I1)
/control-logic/~EXAM SW: RN8.4 (R3), SW18.2 (B), U9.14 (I6)
/control-logic/~LOAD ADDR SW: RN7.3 (R2), SW14.2 (B), U9.4 (I2)
/control-logic/~LOAD EXTD ADDR SW: RN7.4 (R3), SW15.2 (B), U9.6 (I3)
/control-logic/~MD DISP: RN9.5 (R4), SW21.1, U7.2 (I2), U10.6 (I3)
/control-logic/~MQ DISP: RN9.4 (R3), SW21.2, U10.10 (I4)
/control-logic/~PANEL LOCK: RN9.6 (R5), SW22.2 (B), U7.3 (I3)
/control-logic/~STATUS DISP: RN9.2 (R1), SW21.4, U10.14 (I6)
C0 L: J1.7, U12.8
C1 L: J1.8, U12.6
CLK ADDR DISP H: U1.11 (LE), U2.11 (LE), U7.21 (I03)
CLK DATA DISP H: U3.9 (Cp), U4.9 (Cp), U7.22 (IO2)
DX0: J1.34, U3.3 (D0), U5.3 (O1), U9.3 (O1)
DX1: J1.36, U3.4 (D1), U5.5 (O2), U9.5 (O2)
DX2: J1.38, U3.6 (D2), U5.7 (O3), U9.7 (O3)
DX3: J1.40, U3.11 (D3), U5.9 (O4), U9.9 (O4)
DX4: J1.42, U3.13 (D4), U5.11 (O5), U9.11 (O5)
DX5: J1.43, U3.14 (D5), U5.13 (O6), U9.13 (O6)
DX6: J1.45, U4.3 (D0), U6.3 (O1), U10.3 (O1)
DX7: J1.47, U4.4 (D1), U6.5 (O2), U10.5 (O2)
DX8: J1.50, U4.6 (D2), U6.7 (O3), U10.7 (O3)
DX9: J1.48, U4.11 (D3), U6.9 (O4), U10.9 (O4)
DX10: J1.46, U4.13 (D4), U6.11 (O5), U10.11 (O5)
DX11: J1.44, U4.14 (D5), U6.13 (O6), U10.13 (O6)
EMA0: J1.35, U1.3 (D0)
EMA1: J1.41, U1.4 (D1)
EMA2: J1.21, U1.7 (D2)
GND: C1.2, C2.2, C3.2, C4.2, C5.2, C6.2, C7.2, C8.2, C9.2, C10.2, C11.2, C12.2, C13.2, C14.2, C15.2, C16.2, J1.17, J1.18, J1.49, RN1.1 (common), RN2.1 (common), RN3.1 (common), RN4.1 (common), SW1.1 (A), SW2.1 (A), SW3.1 (A), SW4.1 (A), SW5.1 (A), SW6.1 (A), SW7.1 (A), SW8.1 (A), SW9.1 (A), SW10.1 (A), SW11.1 (A), SW12.1 (A), SW13.1 (A), SW14.1 (A), SW15.1 (A), SW16.1 (A), SW17.1 (A), SW18.1 (A), SW19.1 (A), SW20.2 (B), SW21.C, SW22.1 (A), U1.1 (OE), U1.10 (GND), U2.1 (OE), U2.10 (GND), U2.18 (D7), U3.8 (GND), U4.8 (GND), U5.8 (GND), U6.8 (GND), U7.12 (GND), U8.1 (GND), U9.8 (GND), U10.8 (GND), U11.7 (GND), U12.7 (GND), U13.10 (GND)
LXDAR L: J1.14, U13.1 (I1/CLK)
LXMAR L: J1.22, U7.9 (I9)
MA0: J1.30, U1.8 (D3)
MA1: J1.32, U1.13 (D4)
MA2: J1.28, U1.14 (D5)
MA3: J1.26, U1.17 (D6), U13.9 (I9)
MA4: J1.23, U1.18 (D7), U13.8 (I8)
MA5: J1.25, U2.3 (D0), U13.7 (I7)
MA6: J1.27, U2.4 (D1), U13.6 (I6)
MA7: J1.29, U2.7 (D2), U13.5 (I5)
MA8: J1.31, U2.8 (D3), U13.4 (I4)
MA9: J1.33, U2.13 (D4), U7.6 (I6), U13.3 (I3)
MA10: J1.37, U2.14 (D5), U7.5 (I5), U13.2 (I2)
MA11: J1.39, U2.17 (D6), U7.4 (I4), U13.11 (I10/~OE)
unnamed: D1.2 (A), U1.2 (O0)
unnamed: D1.1 (K), RN1.2 (R1)
unnamed: D2.2 (A), U1.5 (O1)
unnamed: D2.1 (K), RN1.3 (R2)
unnamed: D3.2 (A), U1.6 (O2)
unnamed: D3.1 (K), RN1.4 (R3)
unnamed: D4.2 (A), U1.9 (O3)
unnamed: D4.1 (K), RN1.5 (R4)
unnamed: D5.2 (A), U1.12 (O4)
unnamed: D5.1 (K), RN1.6 (R5)
unnamed: D6.2 (A), U1.15 (O5)
unnamed: D6.1 (K), RN1.7 (R6)
unnamed: D7.2 (A), U1.16 (O6)
unnamed: D7.1 (K), RN1.8 (R7)
unnamed: D8.2 (A), U1.19 (O7)
unnamed: D8.1 (K), RN1.9 (R8)
unnamed: D9.2 (A), U2.2 (O0)
unnamed: D9.1 (K), RN2.2 (R1)
unnamed: D10.2 (A), U2.5 (O1)
unnamed: D10.1 (K), RN2.3 (R2)
unnamed: D11.2 (A), U2.6 (O2)
unnamed: D11.1 (K), RN2.4 (R3)
unnamed: D12.2 (A), U2.9 (O3)
unnamed: D12.1 (K), RN2.5 (R4)
unnamed: D13.2 (A), U2.12 (O4)
unnamed: D13.1 (K), RN2.6 (R5)
unnamed: D14.2 (A), U2.15 (O5)
unnamed: D14.1 (K), RN2.7 (R6)
unnamed: D15.2 (A), U2.16 (O6)
unnamed: D15.1 (K), RN2.8 (R7)
unnamed: D16.2 (A), U3.2 (Q0)
unnamed: D16.1 (K), RN3.4 (R3)
unnamed: D17.2 (A), U3.5 (Q1)
unnamed: D17.1 (K), RN3.5 (R4)
unnamed: D18.2 (A), U3.7 (Q2)
unnamed: D18.1 (K), RN3.6 (R5)
unnamed: D19.2 (A), U3.10 (Q3)
unnamed: D19.1 (K), RN3.7 (R6)
unnamed: D20.2 (A), U3.12 (Q4)
unnamed: D20.1 (K), RN3.8 (R7)
unnamed: D21.2 (A), U3.15 (Q5)
unnamed: D21.1 (K), RN3.9 (R8)
unnamed: D22.2 (A), U4.2 (Q0)
unnamed: D22.1 (K), RN4.4 (R3)
unnamed: D23.2 (A), U4.5 (Q1)
unnamed: D23.1 (K), RN4.5 (R4)
unnamed: D24.2 (A), U4.7 (Q2)
unnamed: D24.1 (K), RN4.6 (R5)
unnamed: D25.2 (A), U4.10 (Q3)
unnamed: D25.1 (K), RN4.7 (R6)
unnamed: D26.2 (A), U4.12 (Q4)
unnamed: D26.1 (K), RN4.8 (R7)
unnamed: D27.2 (A), U4.15 (Q5)
unnamed: D27.1 (K), RN4.9 (R8)
unnamed: J2.2, SW24.2 (B)
unnamed: RN5.2 (R1), SW1.2 (B), U5.2 (I1)
unnamed: RN5.3 (R2), SW2.2 (B), U5.4 (I2)
unnamed: RN5.4 (R3), SW3.2 (B), U5.6 (I3)
unnamed: RN5.5 (R4), SW4.2 (B), U5.10 (I4)
unnamed: RN5.6 (R5), SW5.2 (B), U5.12 (I5)
unnamed: RN5.7 (R6), SW6.2 (B), U5.14 (I6)
unnamed: RN6.2 (R1), SW7.2 (B), U6.2 (I1)
unnamed: RN6.3 (R2), SW8.2 (B), U6.4 (I2)
unnamed: RN6.4 (R3), SW9.2 (B), U6.6 (I3)
unnamed: RN6.5 (R4), SW10.2 (B), U6.10 (I4)
unnamed: RN6.6 (R5), SW11.2 (B), U6.12 (I5)
unnamed: RN6.7 (R6), SW12.2 (B), U6.14 (I6)
unnamed: SW23.1 (A), U8.3 (Q)
unnamed: R3.2, SW23.2 (B), U11.3 (C)
unnamed: U7.18 (IO6), U12.3
unnamed: U7.17 (IO7), U12.1
unnamed: U7.16 (IO8), U12.9
unnamed: U7.15 (IO9), U12.5
unnamed: C1.1, U8.5 (CV)
unnamed: R1.2, R2.1, U8.7 (DIS)
unnamed: C6.1, R2.2, U8.2 (TR), U8.6 (THR)
unnamed: U7.23 (IO1), U9.1 (E1), U9.15 (E2), U10.1 (E1), U10.15 (E2)
unnamed: U7.13 (I12), U11.5 (Q)
unnamed: U7.14 (IO10), U11.1 (~R), U11.13 (~R)
unnamed: U7.11 (I11), U11.9 (Q)
unnamed: U7.1 (I1/CLK), U13.13 (IO7)
RD SR L: J1.3, U5.1 (E1), U5.15 (E2), U6.1 (E1), U6.15 (E2)
READ L: J1.11, U7.8 (I8)
RUN LED: D28.1 (K), RN2.9 (R8)
SKIP L: J1.5, U12.4
VCC: C2.1, C3.1, C4.1, C5.1, C7.1, C8.1, C9.1, C10.1, C11.1, C12.1, C13.1, C14.1, C15.1, C16.1, J1.1, J1.2, R1.1, R3.1, R4.1, RN5.1 (common), RN6.1 (common), RN7.1 (common), RN8.1 (common), RN9.1 (common), U1.20 (VCC), U2.20 (VCC), U3.1 (~Mr), U3.16 (VCC), U4.1 (~Mr), U4.16 (VCC), U5.16 (VCC), U6.16 (VCC), U7.24 (VCC), U8.4 (R), U8.8 (VCC), U9.16 (VCC), U10.16 (VCC), U11.2 (D), U11.4 (~S), U11.10 (~S), U11.12 (D), U11.14 (VCC), U12.14 (VCC), U13.20 (VCC)
WR SR L: J1.4, U7.10 (I10)
WRITE L: J1.13, U7.7 (I7)

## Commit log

2023-12-17 Version 1.0
    [2.4mm LED Spacer.stl, Bottom Plate - CF-IDE40.stl, M3 x 12mm Standoff.stl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]
2023-12-18 Fix hole size
    [Slide Switch.stl]
2023-12-18 Fix BOM
2023-12-19 Update 3D printing info
2023-12-19 Fix BOM link typo
2023-12-20 Case tweaks:
    Improve slide switch action
    Increase lug size to move screw holes away from outer edge
    Add lip on base to help center top during assembly
    Tighten tolerance from 0.5mm to 0.3mm for dress panel recess
    Add supports under switch area for front panel
    Add forward stop and right side support for CF card adapter
    [Bottom Plate - CF-IDE40.stl, Top Case.stl]
